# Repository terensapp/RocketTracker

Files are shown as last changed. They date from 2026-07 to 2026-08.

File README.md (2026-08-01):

# Rocket Tracker

A two-part GPS + LoRa tracker for finding your model rocket after it lands. A tiny transmitter rides inside the rocket, reads GPS once a second, and beams position + altitude over long-range radio to a handheld receiver that shows the live fix on an OLED screen and a phone-friendly web page with one-tap turn-by-turn navigation to the rocket.

No cellular network, no WiFi infrastructure, no subscription — just point-to-point radio that works in a farm field just as well as it works anywhere else.

## How it works

- **Transmitter** (rides in the rocket): reads lat/lon/altitude/satellite count/fix quality (HDOP)/battery level off a GPS module and its own sensors, and sends a 23-byte packet over LoRa once per second.
- **Receiver** (stays in your hand): listens for those packets, shows the latest fix (plus HDOP, so you know how much to trust it) plus height-above-pad and max-altitude-reached on a small OLED, and hosts its own WiFi hotspot with a web page — connect your phone to it and tap "Navigate to Rocket" (opens Google Maps) to walk straight to the rocket, or watch a live altitude graph of the flight so far. No power switch on the board, but holding the top PRG button for a second puts it to sleep (and pressing it again wakes it back up), so it isn't draining its battery between launches. It also shows the transmitter's battery level, which hitches a ride in every LoRa packet, so you can check there's plenty of charge before walking out to the pad. A "New Launch" button on the web page resets the altitude graph and baseline for the next flight, no power-cycling required.

Full technical detail — packet format, pin mappings, radio settings — is in [`SETUP_README.md`](SETUP_README.md) and in the comments at the top of each `.ino` file.

<p align="center">
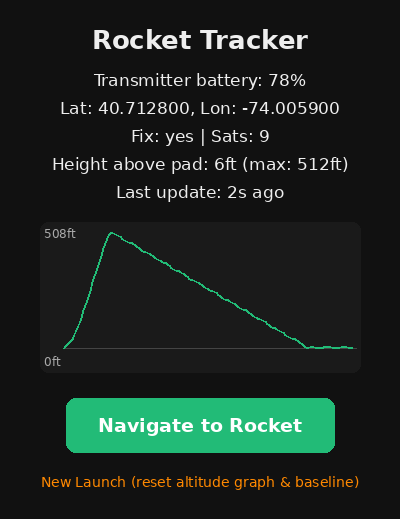
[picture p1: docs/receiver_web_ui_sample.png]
Sample of the receiver's web page, showing battery, GPS fix, altitude graph, and navigation button
  
</p>

<p align="center"><em>Illustrative mockup with sample flight data (not a real device screenshot) — shows the receiver's web page layout: battery, GPS fix, live altitude graph, and the "Navigate to Rocket" / "New Launch" buttons.</em></p>

## Repo contents

| Path | What it is |
| --- | --- |
| `rocket_transmitter/rocket_transmitter.ino` | Flashes onto the board that rides in the rocket (Feather M0 build) |
| `rocket_transmitter_wireless_tracker/rocket_transmitter_wireless_tracker.ino` | Alternative transmitter sketch for the smaller Heltec Wireless Tracker V2 build (recommended over CubeCell) |
| `rocket_transmitter_cubecell/rocket_transmitter_cubecell.ino` | Legacy alternative transmitter sketch for the CubeCell GPS build — see the note in its BOM section before buying this board |
| `rocket_receiver/rocket_receiver.ino` | Flashes onto the handheld receiver (works with any transmitter build) |
| `SETUP_README.md` | Step-by-step flashing and bench-test guide |
| `enclosures/transmitter_case.scad` | Parametric 3D-printable case for the Feather M0 transmitter stack |
| `enclosures/transmitter_case_wireless_tracker.scad` | Parametric 3D-printable case for the Wireless Tracker V2 transmitter |
| `enclosures/transmitter_case_cubecell.scad` | Parametric 3D-printable case for the CubeCell GPS transmitter (legacy) |

## Bill of Materials

Two boards, no soldering beyond an optional antenna wire. Prices are approximate and will drift.

### Transmitter (goes in the rocket) — ~$69

| Part | Price | Link |
| --- | --- | --- |
| Adafruit Feather M0 with RFM95 LoRa Radio (900MHz) | $34.95 | [adafruit.com/product/3178](https://www.adafruit.com/product/3178) |
| Adafruit Ultimate GPS FeatherWing | $24.95 | [adafruit.com/product/3133](https://www.adafruit.com/product/3133) |
| 3.7V 300mAh LiPo, generic "302040" size (3.0 x 20 x 40mm, JST-PH connector) — a standard size code widely sold on Amazon/AliExpress, not an Adafruit part; search "302040 300mAh lipo" | ~$7-9 | generic |
| 915MHz spring antenna — 17.5mm long, 2.15dBi gain, 50Ω impedance, solders directly to the board's ANT pad (or solder your own quarter-wave wire instead — the sketch comments explain the length) | $0.95 | [adafruit.com/product/4269](https://www.adafruit.com/product/4269) |
| Micro USB cable, for flashing | — | any micro USB cable |

Optional: a CR1220 coin cell ([adafruit.com/product/380](https://www.adafruit.com/product/380), $0.95) gives the GPS module a warm-start battery backup — not required, just speeds up subsequent fixes.

### Receiver (stays in your hand) — check listing for price

| Part | Price | Link |
| --- | --- | --- |
| Meshnology N30, 2-pack (ESP32-S3 + SX1262, includes 1100mAh battery + case + 915MHz antenna per unit) | check listing | [Amazon](https://www.amazon.com/V3-Development-1100mAh-Battery-Protect/dp/B0F1CXG94J) |
| USB-C cable, for flashing | — | any USB-C cable |

You only need one N30 for the receiver — the Amazon listing sells them as a 2-pack, so the second board makes a handy spare or a second ground unit. It ships as a kit (board, battery, case, antenna as separate pieces you assemble) rather than pre-built — expect a few minutes of snapping it together, not soldering.

**Region note:** both sketches default to 915MHz (US). Outside the US, buy 868MHz-band antennas instead and change `LORA_FREQ_MHZ` to `868.0` in both `.ino` files — see the "Frequency/region" note in `SETUP_README.md`.

### Optional: a case for the transmitter

`enclosures/transmitter_case.scad` is a 3D-printable case that holds the whole transmitter stack — board, battery, and a cutout for an inline power switch. See the "3D-printed transmitter case" section in [`SETUP_README.md`](SETUP_README.md) for details and printing notes.

### Alternative transmitter: Wireless Tracker V2 (smaller form factor, recommended)

If the Feather M0 stack is too tall to fit your airframe, `rocket_transmitter_wireless_tracker/rocket_transmitter_wireless_tracker.ino` is an alternative transmitter sketch for the **Heltec Wireless Tracker V2** — one small board with the MCU, LoRa radio (plus an RF front-end amplifier for extra range), and GNSS all built in, instead of three stacked boards. It sends the exact same packet format, so it works with the **same receiver sketch, unmodified**, and uses **RadioLib** — the same LoRa library the receiver already uses, unlike the CubeCell alternative below. This board also has a small onboard TFT display, which this sketch uses to show live GPS/radio status — handy for bench-testing outdoors on battery power without a laptop tethered for the Serial Monitor. The backlight is off by default to save battery; press the board's user button to check status before a launch, press again to turn it off. See "Alternative build: Wireless Tracker V2" in [`SETUP_README.md`](SETUP_README.md) for the full picture.

| Part | Price | Link |
| --- | --- | --- |
| Heltec Wireless Tracker V2 | ~$23–31 (compare Heltec's own store vs. Amazon/AliExpress resellers) | [heltec.org/project/wireless-tracker-v2](https://heltec.org/project/wireless-tracker-v2/) |
| 3.7V 300mAh LiPo, "302040" size — same JST-SH 1.25mm pitch connector as the CubeCell build | ~$7-9 | generic |
| Included spring LoRa antenna (ships with the board) — GNSS uses a built-in antenna on the board itself, no separate antenna needed for that | — | included |
| SS12D00-G4 mini slide switch, spliced inline into the battery lead — same part as the CubeCell build's switch mount | ~$3-6 for a pack | generic |
| USB-C cable, for flashing | — | any USB-C cable |

`enclosures/transmitter_case_wireless_tracker.scad` is the matching case — same snap-lid-and-glue closure, parachute tie tab, slim clearances, and rounded corners as the CubeCell case, sized for this board instead.

### Legacy alternative: CubeCell GPS

`rocket_transmitter_cubecell/rocket_transmitter_cubecell.ino` and `enclosures/transmitter_case_cubecell.scad` are still in this repo and still work, but **the Wireless Tracker V2 build above is recommended instead** for two reasons: Heltec lists the CubeCell ASR650x series as "Phaseout" on their own docs site, and this board's onboard GPS antenna has multiple independent weak/dead-on-arrival reports on Heltec's community forum. If you already have a CubeCell GPS board, it's documented in full in `SETUP_README.md`, including a workaround for the antenna issue.

| Part | Price | Link |
| --- | --- | --- |
| Heltec CubeCell GPS-6502 (HTCC-AB02S) | ~$25.80–25.90 | [heltec.org/project/htcc-ab02s](https://heltec.org/project/htcc-ab02s/) |
| 3.7V 300mAh LiPo, "302040" size — **check the connector**: this board uses JST-SH 1.25mm pitch, not the JST-PH 2.0mm pitch on the Feather build | ~$7-9 | generic |
| u.FL/IPEX stub antenna, 902-928MHz, 3dBi, direct-mount (no pigtail needed) | $6.49 | [DigiKey #1173-1023-ND](https://www.digikey.com/en/products/detail/ttm-technologies-inc/66089-0906/3069145) |
| SS12D00-G4 mini slide switch, spliced inline into the battery lead — a common generic part, search that name on Amazon/AliExpress/eBay; the case's switch pocket is sized to its body/lever dimensions (see `SETUP_README.md`) | ~$3-6 for a pack | generic |
| Micro USB cable, for flashing | — | any micro USB cable |

## Getting started

1. Buy the parts above.
2. Follow [`SETUP_README.md`](SETUP_README.md) for board packages, libraries, flashing steps, and a bench-test checklist — do the bench test before anything goes near a launch pad.
3. Fly, land, open the receiver's web page, tap navigate, go find your rocket.

## Status

The Feather M0 transmitter, the Wireless Tracker V2 transmitter, and the receiver are all compile-verified (Adafruit SAMD core / esp32 core, RadioLib/TinyGPSPlus/U8g2/Adafruit GFX+ST7735 — zero errors, zero warnings) but not yet flight-tested on real hardware. The CubeCell GPS transmitter alternative has also been compile-verified against the real CubeCell board package and toolchain (zero errors) — see the caveat about one packaging-only step in `SETUP_README.md`. Bench-test thoroughly before a launch, regardless of which transmitter build you use.

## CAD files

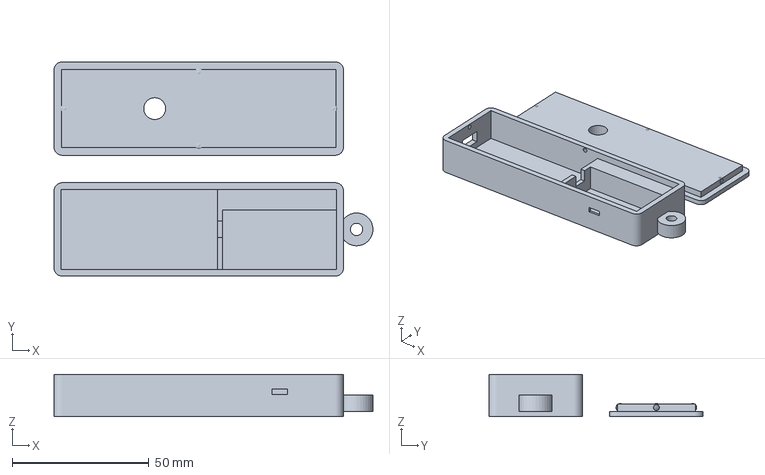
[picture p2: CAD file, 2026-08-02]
enclosures/transmitter_case_cubecell.3mf
116.5 x 78.2 x 15.5 mm

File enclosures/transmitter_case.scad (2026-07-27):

// ==========================================================================
// ROCKET TRACKER - TRANSMITTER CASE
// ==========================================================================
// Holds: Adafruit Feather M0 w/ RFM95 LoRa (900MHz, product 3178) with the
// Adafruit Ultimate GPS FeatherWing (product 3133) stacked on top, a 3.7V
// 300mAh LiPo (generic "302040" size, ~40 x 20 x 3mm - see battery bay
// section below), a hole for a spring antenna to poke through, and a
// panel-mount cutout for an inline power switch spliced into the battery
// lead.
//
// CLOSURE: the lid press-fits into a lip on the base, with 4 small snap
// bumps (see bump_r/bump_protrude) that give it a bit of a "click" and
// hold it shut for handling - it's meant to be glued the rest of the way
// once you've test-fit everything, not screwed. No screw bosses sticking
// out means a noticeably smaller footprint, which matters if this needs
// to fit down a rocket's airframe.
//
// RECOVERY: there's a molded tie tab on the battery-bay end with a round
// hole through it (see tie_hole_d) for a loop of paracord or shock cord,
// so the transmitter stays attached to the parachute/harness instead of
// becoming its own separate ballistic object on the way down.
//
// HOW TO USE THIS FILE
//   1. Open in OpenSCAD (openscad.org - free, all platforms).
//   2. Set the `part` variable below to "base" or "lid", press F6 (render),
//      then File > Export > Export as STL. Do this once for each part.
//   3. Leaving `part` set to "both" just previews them side by side so you
//      can see how everything lines up - don't export an STL in that mode,
//      the two parts would come out as one fused blob.
//
// IMPORTANT - DIMENSIONS ARE BEST-EFFORT, NOT MEASURED FROM YOUR HARDWARE
//   Board outline, header spacing, and connector positions below come from
//   Adafruit's published Feather specification and product pages, not from
//   calipers on your actual boards. The pocket and cutouts are sized with
//   generous clearance (see the *_fit variables) specifically so small
//   errors here don't turn into a part that doesn't fit. Even so: print the
//   base first, test-fit your actual boards and battery in it BEFORE
//   printing the lid or trimming any clearance down. Cheap, fast filament
//   (low infill, no supports needed for this design) makes a test print
//   painless compared to re-measuring everything by hand up front.
//
// WHERE THE ANTENNA EXITS
//   Adafruit's guide has you solder the antenna into the "ANT" pad on the
//   right-hand long edge of the Feather (USB connector oriented at the
//   top), positioned toward the end of the board opposite USB (that's
//   where the RFM95 radio module itself sits). The exit hole below is on
//   that same long edge, close to the far end - NOT on the far end wall
//   itself, because that wall is shared with the battery bay right next
//   to it, and the antenna's lead (about 17.5mm total) isn't long enough
//   to reach all the way across the battery bay to the case's true far
//   end. `ant_hole_y` controls exactly how close to the end it sits -
//   check where your antenna is actually soldered before printing.
// ==========================================================================

part = "both"; // "base", "lid", or "both" (preview only)

// ---------------------------------------------------------------------
// Feather board stack (M0 LoRa + GPS FeatherWing)
// ---------------------------------------------------------------------
feather_l          = 50.8;  // 2.0in - Feather board length (Adafruit spec)
feather_w          = 22.9;  // 0.9in - Feather board width
board_fit          = 1.0;   // clearance added around the board footprint
pcb_t              = 1.6;   // typical PCB thickness (both boards)
header_gap         = 8.6;   // vertical gap between the two boards once the
                             // GPS wing is plugged into standard-height
                             // female headers on the M0 - also has to fit
                             // the GPS wing's coin-cell holder on its
                             // underside, which is why this isn't tighter
under_board_clear  = 2.5;   // clearance below the M0 for solder joints/pins
top_stack_clear    = 7.0;   // clearance above the GPS wing for its patch
                             // antenna (~4mm tall) plus a little headroom

stack_h = under_board_clear + pcb_t + header_gap + pcb_t + top_stack_clear;

// Feather mounting holes: Adafruit's spec says "0.1in holes at each
// corner" - taken here as 2.54mm inset from every edge, giving the
// commonly-seen 1.8in x 0.7in (45.7 x 17.8mm) hole spacing. Worth
// double-checking against your actual board; these posts are support/
// registration features, not the only thing holding the stack in place.
hole_inset  = 2.54;
post_dia    = 6.0;   // support nub diameter at each estimated hole location
                      // (solid bumps the PCB rests on - not threaded, just
                      // support; add your own screw holes here if you've
                      // verified the real hole positions on your board)

// ---------------------------------------------------------------------
// Battery bay - sized for a 3.7V 300mAh LiPo, generic "302040" size code
// (a standard, widely-sold LiPo footprint - the digits are the physical
// dimensions: 3.0mm thick x 20mm wide x 40mm long). Not an Adafruit part
// number - these are commonly sold on Amazon/AliExpress with a JST-PH
// connector, search "302040 300mAh lipo". Swap batt_l/batt_w/batt_t below
// if your actual battery's printed dimensions differ.
// ---------------------------------------------------------------------
batt_l = 40.0;
batt_w = 20.0;
batt_t = 3.0;
batt_fit = 1.2; // clearance around the battery so it slides in easily

// ---------------------------------------------------------------------
// Case shell
// ---------------------------------------------------------------------
wall   = 2.5;   // a bit thicker than a typical small enclosure - this has
                 // to survive a parachute landing - but slim enough to
                 // help the whole thing fit down an airframe
floor  = 2.0;
lid_t  = 2.0;
lip_h  = 3.0;    // depth of the base's lip that the lid seats into
lip_gap = 0.3;   // general clearance between lid skirt and base lip, sized
                 // for an easy push-together fit - the snap bumps below
                 // are what actually give it resistance/a "click", not a
                 // tight fit across the whole perimeter (which is harder
                 // to guarantee across different printers)

// Small interference bumps on the lid's skirt (one per side, at the
// midpoint) that the base's lip has to flex slightly to accept - gives a
// "snap" you can feel going on, without relying on the whole perimeter
// being a precise press-fit. This is meant to hold the lid on for
// handling and a test-fit, then get glued for flight - not to be a
// resealable connector.
bump_r        = 1.5;  // bump sphere radius
bump_protrude = 0.35; // how far the bump sticks out past the skirt face

// Internal partition between the electronics bay and the battery bay -
// the battery's JST wire just runs over the top of it, no hole needed.
divider_w = 2.0;
divider_gap_h = 6.0; // leave a gap above the divider for the JST wire

// ---------------------------------------------------------------------
// USB cutout (micro USB on the Feather M0, top/short edge of the board)
// ---------------------------------------------------------------------
usb_w = 10.0;
usb_h = 5.0;
usb_offset = 6.0; // distance from the electronics-bay side wall to the
                   // near edge of the cutout - Feather's USB connector
                   // sits close to the left edge of the board; nudge this
                   // to match your board if it's off

// ---------------------------------------------------------------------
// Antenna exit hole (right-hand long edge of the Feather, near the end
// opposite USB - see "WHERE THE ANTENNA EXITS" at the top of this file).
// Sized for Adafruit's Simple Spring Antenna - 915MHz (product 4269):
// 17.5mm long, 0.8mm wire gauge wound into a coil - the coil's outer
// diameter isn't published, so ant_hole_d below is a generous estimate
// with clearance built in, not a measured fit.
// ---------------------------------------------------------------------
ant_hole_d = 5.0;
ant_hole_y = 0.9; // fraction along that edge's length - 0 = USB end,
                   // 1 = far/divider end. 0.9 keeps it close to the far
                   // end (where the radio module is) with a little margin
                   // from the corner for wall strength.
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

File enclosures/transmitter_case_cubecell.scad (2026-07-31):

// ==========================================================================
// ROCKET TRACKER - TRANSMITTER CASE (CubeCell GPS all-in-one alternative)
// ==========================================================================
// Holds: Heltec CubeCell GPS, HTCC-AB02S (one board - MCU, SX1262 LoRa radio,
// GPS, and OLED all integrated, no stacking), a 3.7V 300mAh LiPo (generic
// "302040" size), a hole for a u.FL/IPEX antenna pigtail to exit, and a
// keyed pocket that holds an SS12D00-G4 slide switch spliced into the
// battery lead. This is the companion case for rocket_transmitter_cubecell.ino
// - see enclosures/transmitter_case.scad instead if you're building the
// Feather M0 version (three-board stack, spring antenna soldered direct).
//
// WHY THIS IS SMALLER: the Feather M0 build stacks three boards (M0 + GPS
// FeatherWing + battery) with headroom between them for header pins and a
// patch antenna. CubeCell GPS puts the MCU, radio, and GPS on one board, so
// this case only needs to be as tall as one PCB plus its tallest connector,
// not a whole stack. Rough numbers: this case's footprint is about 34mm
// wide x 15.5mm tall, versus 30mm x 26mm for the Feather version - shallower,
// which matters more than raw length for sliding into a narrow airframe.
//
// SLIMMED DOWN + ROUNDED CORNERS: the board/battery pocket clearances
// (`board_fit`, `batt_fit`, `board_vert_clear`) were tightened to shave a
// couple mm off every outer dimension - still a snug hand-fit, not a
// press-fit, since this case is glued shut once and not reopened. The 4
// vertical corners are also rounded (`case_corner_r`) instead of sharp
// 90-degree edges - more comfortable to handle, and a rounded rectangle's
// bounding circle is smaller than a sharp one's, which helps it slide into
// a round airframe tube. Only the outer surfaces are rounded; every
// interior cavity (pockets, cutouts, lip/skirt) stays a plain rectangle,
// since they're all inset `wall` from the edges - comfortably clear of the
// rounding - and don't need to match it for anything to seat correctly.
//
// CLOSURE / RECOVERY: same snap-lid-and-glue closure and parachute tie tab
// as the Feather case - see that file's header comment for the reasoning,
// not repeated here. One difference: this case's snap bumps also have a
// matching detent dimple cut into the base's lip cavity for each one to
// seat into (see `bump_groove_r` below) - the Feather case's bumps just
// press against a flat wall, which is fine there but wasn't giving a
// reliable click on this smaller case, so a real detent was added here.
//
// HOW TO USE THIS FILE
//   1. Open in OpenSCAD (openscad.org - free, all platforms).
//   2. Set the `part` variable below to "base" or "lid", press F6 (render),
//      then File > Export > Export as STL. Do this once for each part.
//   3. Leaving `part` set to "both" just previews them side by side - don't
//      export an STL in that mode.
//
// IMPORTANT - DIMENSIONS ARE BEST-EFFORT, NOT MEASURED FROM YOUR HARDWARE
//   The board envelope (55.9 x 27.9 x 9.5mm) comes from Heltec's published
//   spec sheet for HTCC-AB02S, not calipers on your actual board. Print the
//   base first, test-fit before printing the lid.
//
// WHERE THE ANTENNA EXITS - READ THIS ONE CAREFULLY
//   Unlike the Feather build (a spring antenna soldered directly to a fixed
//   pad), CubeCell GPS has a u.FL/IPEX antenna connector - you'll need an
//   IPEX-pigtail antenna (see the BOM note in the README) rather than a
//   solder-in spring antenna. Heltec's pin map diagram shows roughly where
//   that connector sits, but wasn't precise enough to trust for a tight
//   side-wall cutout. So instead of guessing a side position and risking a
//   hole that misses the connector, the antenna hole below is cut through
//   the TOP of the LID, sized generously (8mm) and centered over the board
//   - the u.FL pigtail is a thin, flexible cable, so it can bend to reach an
//   opening almost anywhere above the board. Nudge `ant_hole_x_frac` /
//   `ant_hole_y_frac` below if your test-fit shows the connector is
//   noticeably off-center, but don't assume you need to before checking.
//
// WHERE THE SWITCH LIVES
//   The switch mount is a keyed pocket in the battery bay's front wall (the
//   long wall at y=0), centered along that bay's length - not on the end
//   wall the tie tab is bolted to. Earlier versions of this case put a
//   switch cutout on that end wall, right next to the tie tab, which looked
//   like a stray unexplained hole and put a hole through the same wall the
//   tie tab has to stay solid for. Moving it to the battery bay's side wall
//   fixes both problems. The pocket is two nested cuts: a narrow slot
//   through the outer face sized only for the slide lever to poke through
//   and travel in, and a wider, shallower pocket behind it (open to the
//   battery bay's interior) sized to capture the switch body. The body
//   can't pull out through the narrow outer slot, and two small retention
//   bumps (same idea as the lid's snap bumps, just smaller) protrude into
//   the pocket from its top and bottom faces - the switch body has to press
//   past them to seat, then they nest against its top/bottom face and hold
//   it with a "click", no glue required (though a dab is still fine if you
//   want extra insurance) - see the "Slide switch mount" parameters below
//   for the dimensions, taken from the SS12D00-G4
//   manufacturer drawing (body 8.7 x 3.7 x 3.7mm, lever 1.5 x 1.5 x 4mm).
//   The 3-pin through-hole legs on the underside of that switch aren't used
//   here - the switch is wired inline into the battery lead by hand, not
//   soldered to a PCB, so only the body and lever envelope matter for the
//   case. `sw_travel` is an assumed slide throw, not from the drawing (which
//   doesn't dimension it) - test-fit and adjust if your switch's actual
//   throw differs.
// ==========================================================================

part = "both"; // "base", "lid", or "both" (preview only)

// ---------------------------------------------------------------------
// CubeCell GPS board (HTCC-AB02S) - one-piece board, no stacking
// ---------------------------------------------------------------------
board_l   = 55.9;  // Heltec spec: overall board length
board_w   = 27.9;  // Heltec spec: overall board width
board_h   = 9.5;   // Heltec spec: overall board height, including the
                    // onboard OLED, connectors, and any other tallest part
board_fit = 0.6;    // clearance added around the board footprint - tightened
                     // from 1.0mm to slim the case down; still a snug hand-fit,
                     // not a press-fit, since this is glued shut once anyway
board_vert_clear = 1.0; // headroom above the board's tallest point - was 1.5mm

pocket_h = board_h + board_vert_clear;

// No verified mounting-hole spec is published for this board, so this
// design deliberately skips screw-post nubs (unlike the Feather case, which
// had Adafruit's documented hole spacing to work from) rather than guess
// hole positions that might be wrong. The board is held by a snug pocket
// fit in X/Y and the lid's underside in Z - fine for a glued-shut case that
// isn't opened repeatedly. Add your own posts here if you've measured your
// actual board's mounting holes.

// ---------------------------------------------------------------------
// Battery bay - sized for a 3.7V 300mAh LiPo, generic "302040" size code
// (3.0mm thick x 20mm wide x 40mm long). Same battery as the Feather build
// - see that file's comment for sourcing notes. One difference: CubeCell
// GPS's onboard battery connector is JST-SH 1.25mm pitch (2-pin), NOT the
// JST-PH 2.0mm pitch used on the Feather - double check which connector
// your battery actually ships with (see the BOM note) before ordering.
// ---------------------------------------------------------------------
batt_l = 40.0;
batt_w = 20.0;
batt_t = 3.0;
batt_fit = 0.8; // was 1.2mm - tightened along with board_fit to slim the case

// ---------------------------------------------------------------------
// Case shell
// ---------------------------------------------------------------------
wall   = 2.5;
floor  = 2.0;
lid_t  = 2.0;
lip_h  = 3.0;
lip_gap = 0.3;
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

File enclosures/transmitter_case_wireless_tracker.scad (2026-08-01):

// ==========================================================================
// ROCKET TRACKER - TRANSMITTER CASE (Heltec Wireless Tracker V2 alternative)
// ==========================================================================
// Holds: Heltec Wireless Tracker V2 (one board - ESP32-S3 MCU, SX1262 LoRa
// radio + RF front-end amplifier, UC6580 GNSS, and TFT display all
// integrated, no stacking), a 3.7V 300mAh LiPo (generic "302040" size), a
// hole for the LoRa antenna to exit, and a keyed pocket that holds an
// SS12D00-G4 slide switch spliced into the battery lead. This is the
// companion case for rocket_transmitter_wireless_tracker.ino - see
// enclosures/transmitter_case.scad (Feather M0) or
// enclosures/transmitter_case_cubecell.scad (CubeCell GPS, legacy) for the
// other two transmitter builds in this repo.
//
// WHY THIS BOARD INSTEAD OF CUBECELL: CubeCell GPS is on Heltec's own
// "Phaseout" list, and its onboard GPS antenna has multiple independent
// weak/dead-on-arrival reports. Wireless Tracker V2 uses a different,
// better-regarded GNSS chip (UC6580) and is an actively-sold, actively-
// supported product - see SETUP_README.md for the full comparison.
//
// GNSS ANTENNA - NO HOLE NEEDED FOR IT
// Unlike the CubeCell case, this one only has ONE antenna hole, for LoRa.
// This board's GNSS antenna is a built-in LDS (laser-direct-structuring)
// antenna etched right onto the board - no external antenna or hole needed
// for normal use. If you ever do the resistor-rework Heltec documents for
// switching to an external GNSS antenna, you'd need to add a second hole
// yourself - not included here since it's not needed by default.
//
// WHERE THE LORA ANTENNA EXITS
// Cut through the TOP of the LID, same reasoning as the CubeCell case:
// Heltec doesn't publish a precise connector position, and the included
// antenna has some flex in its stub, so a generous, centered top hole
// avoids needing to guess an exact side-wall position that might miss.
// Nudge `ant_hole_x_frac` / `ant_hole_y_frac` below if your test-fit shows
// the connector is noticeably off-center.
//
// HOW TO USE THIS FILE
//   1. Open in OpenSCAD (openscad.org - free, all platforms).
//   2. Set the `part` variable below to "base" or "lid", press F6 (render),
//      then File > Export > Export as STL. Do this once for each part.
//   3. Leaving `part` set to "both" just previews them side by side - don't
//      export an STL in that mode.
//
// IMPORTANT - DIMENSIONS ARE BEST-EFFORT, NOT MEASURED FROM YOUR HARDWARE
//   The board envelope (53.0 x 25.4 x 10.3mm) is the larger of two
//   slightly-different numbers Heltec publishes for this board across
//   their store page and docs wiki - taken conservatively so the pocket
//   errs on the roomy side. Print the base first, test-fit before printing
//   the lid.
//
// WHERE THE SWITCH LIVES
//   Same keyed-pocket switch mount as the CubeCell case, same SS12D00-G4
//   part, same reasoning - see that file's header comment if you want the
//   full explanation. Quick summary: a narrow outer slot for the slide
//   lever only, a wider inner pocket for the switch body (captured, can't
//   pull through the narrow slot), and two small retention bumps that snap
//   the body in place with a "click." Centered on the battery bay's front
//   wall, away from the tie tab.
// ==========================================================================

part = "both"; // "base", "lid", or "both" (preview only)

// ---------------------------------------------------------------------
// Heltec Wireless Tracker V2 board - one-piece board, no stacking
// ---------------------------------------------------------------------
board_l   = 53.0;  // larger of Heltec's two published lengths (52.0/53.0)
board_w   = 25.4;  // Heltec spec: overall board width
board_h   = 10.3;  // larger of Heltec's two published heights (9.37/10.26),
                    // including the TFT glass, USB-C connector, and the
                    // shielded LoRa/GNSS chip cans
board_fit = 0.6;    // clearance added around the board footprint - snug
                     // hand-fit, not a press-fit, fine for a glued-shut case
board_vert_clear = 1.5; // headroom above the board's tallest point - a bit
                         // more than the CubeCell case's, since this board
                         // has more raised hardware (USB-C, shield cans,
                         // TFT) and its exact height breakdown isn't published

pocket_h = board_h + board_vert_clear;

// No verified mounting-hole spec is published for this board, so - same as
// both other cases in this repo - this design skips screw-post nubs and
// relies on a snug pocket fit in X/Y and the lid's underside in Z. Add your
// own posts here if you've measured your actual board's mounting holes.

// ---------------------------------------------------------------------
// Battery bay - sized for a 3.7V 300mAh LiPo, generic "302040" size code
// (3.0mm thick x 20mm wide x 40mm long). Same battery and same JST-SH
// 1.25mm pitch connector as the CubeCell build - see that file's comment
// for sourcing notes.
// ---------------------------------------------------------------------
batt_l = 40.0;
batt_w = 20.0;
batt_t = 3.0;
batt_fit = 0.8;

// ---------------------------------------------------------------------
// Case shell
// ---------------------------------------------------------------------
wall   = 2.5;
floor  = 2.0;
lid_t  = 2.0;
lip_h  = 3.0;
lip_gap = 0.3;

// Rounded corners - see the CubeCell case's comment for the full reasoning
// (comfort + helps sliding into a round airframe tube). Carried over here
// from day one instead of being a later retrofit.
case_corner_r = 3.0;

bump_r        = 1.5;
bump_protrude = 0.5;   // net interference tuned the same way as the
                        // CubeCell case's lid bumps - see that file's
                        // comment for why 0.5 instead of a smaller value
bump_groove_r     = 1.1;
bump_groove_depth = 0.65;
bump_groove_inset = bump_groove_r - bump_groove_depth;

divider_w = 2.0;
divider_gap_h = 5.0; // gap above the divider for the battery's JST wire to
                      // cross over

// ---------------------------------------------------------------------
// USB-C cutout - generously sized (same envelope as the CubeCell case's
// micro-USB cutout, which comfortably fits USB-C's slightly larger
// connector body too).
// ---------------------------------------------------------------------
usb_w = 10.0;
usb_h = 5.0;
usb_center_bias = 0.0; // mm to shift the cutout off-center, + = toward the
                        // battery/divider end - nudge if your board's port
                        // isn't centered on the board width
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

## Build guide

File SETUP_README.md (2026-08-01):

# Rocket Tracker — Setup Guide

Two sketches:

- `rocket_transmitter/rocket_transmitter.ino` — flashes onto the **Adafruit Feather M0 + RFM95 LoRa (900MHz) + GPS FeatherWing** stack. Lives in the rocket.
- `rocket_receiver/rocket_receiver.ino` — flashes onto the **Meshnology N30 (ESP32-S3 + SX1262)**. Handheld unit.

Both sketches have been compile-verified against the real toolchain (Adafruit SAMD core + esp32 core, RadioLib/TinyGPSPlus/U8g2) — zero errors, zero warnings. Compilation only proves the code builds, though, not that it works on real hardware — do the bench test in step 6 before anything goes near a launch pad.

## 1. Install Arduino IDE

Download from arduino.cc if you don't have it already (2.x recommended).

## 2. Install board packages

**File > Preferences > Additional Board Manager URLs**, add both (comma-separated, or one per line depending on your IDE version):

```
https://adafruit.github.io/arduino-board-index/package_adafruit_index.json
https://raw.githubusercontent.com/espressif/arduino-esp32/gh-pages/package_esp32_index.json
```

The Adafruit URL is required for the transmitter's board — without it, "Adafruit SAMD Boards" won't show up in Boards Manager at all.

Then **Tools > Board > Boards Manager**:

- Install **"Adafruit SAMD Boards"** (for the transmitter)
- Install **"esp32" by Espressif Systems** (for the receiver)

## 3. Install libraries

**Tools > Manage Libraries**, install:

- `RadioLib` (Jan Gromeš) — used by both sketches
- `TinyGPSPlus` (Mikal Hart) — transmitter only
- `U8g2` (oliver) — receiver only

## 4. Flash the transmitter

1. Plug the Feather M0 (with the GPS FeatherWing already stacked on top) into USB.
2. **Tools > Board** → select "Adafruit Feather M0"
3. Select the right **Port**
4. Open `rocket_transmitter.ino`, hit Upload
5. Open Serial Monitor at 115200 baud — you should see it printing GPS status. Note: it'll report `fix=0` indoors/near windows until it gets a clear sky view; GPS can take 30 seconds to a few minutes on a cold start.

## 5. Flash the receiver

1. Plug the Meshnology N30 into USB-C.
2. **Tools > Board** → select "ESP32S3 Dev Module"
3. Select the right **Port**. If you want Serial Monitor output over the same USB-C cable, also set **Tools > USB CDC On Boot > Enabled** (this board uses ESP32-S3's native USB, so without this setting the serial output has nowhere to go).
4. Open `rocket_receiver.ino`, hit Upload
5. The OLED should light up and show "Waiting for signal..." — if it stays blank, see the pin troubleshooting note below.

## 6. Test on the bench before flying

1. Power both boards up near each other.
2. The transmitter's onboard LED should blink briefly once per second (each successful send).
3. The receiver's OLED should update with lat/lon once the transmitter has a GPS fix — try this near a window or outdoors, GPS won't get a fix indoors.
4. On your phone, connect to WiFi network `RocketTracker` (password `findmyrocket`), then open `http://192.168.4.1` in a browser. You should see the coordinates and a green "Navigate to Rocket" button — tapping it always opens Google Maps (the app if it's installed, otherwise the website), regardless of phone.
5. Walk the transmitter away from the receiver in a straight line to get a rough real-world range estimate before your first launch. Don't assume the spec-sheet range — trees, buildings, and antenna orientation all matter.

## Altitude

GPS gives you altitude for free alongside lat/lon, so the receiver now shows it two ways:

- **Height above pad** — the receiver treats the *first* valid fix it ever receives as ground level, then reports everything after that as a delta from it. This is far more useful mid-search than raw GPS altitude (which is Mean Sea Level, an unfamiliar number tied to your local elevation, not the rocket's).
- **Max height reached** — since altitude is already streaming in every second, tracking the highest value seen is essentially free apogee tracking, no separate altimeter needed.

**This means the transmitter needs to be powered on while the rocket is already sitting on the pad, before launch** — that's the moment its GPS altitude becomes the "zero" baseline. Both the OLED and the web page show "H:" (height above pad) and "Max:" once a baseline is set; before that, they fall back to showing raw MSL altitude.

Two honest caveats: GPS altitude is less accurate than horizontal position — commonly off by 30-50 feet without differential correction — so treat this as a rough estimate, not a precision altimeter reading. Also, the baseline and max height both reset if the receiver reboots, so if you're running multiple flights in a day, power-cycle the receiver right before each new launch to re-zero it.

Everything shown to you — on the OLED, the web page, and in this guide — is in feet. Internally the GPS and the radio packet still use meters (that's what GPS hardware natively reports), the conversion just happens once, right before anything gets displayed.

### Live altitude graph

Sample of the receiver's web page with the altitude graph

*Illustrative mockup with sample flight data, not a real device screenshot — shows roughly what the web page looks like once you have a flight logged.*

The web page also draws a running graph of height-above-pad for the whole flight so far — no separate app, it's a plain HTML5 canvas the receiver draws itself, since the phone has no internet access while connected to the receiver's hotspot (a CDN-hosted charting library just wouldn't load). The graph, the max-height reading, and the altitude baseline all reset together — either by power-cycling the receiver, or by tapping **New Launch** at the bottom of the web page, which is the faster option if you're running multiple flights in a day.

The receiver keeps up to 30 minutes of altitude history per flight (one point per second, ~7KB of RAM — this board has hundreds of KB free, so it's not a real constraint). If a flight somehow runs past that, new points stop recording rather than erasing the earlier ones, so you still keep the actual ascent/descent profile instead of losing it.

## GPS precision

Both the OLED and the web page now show **HDOP** (horizontal dilution of precision) next to the fix — this is the actual accuracy number, separate from "has a fix" or satellite count. A GPS can report a valid fix with 9 satellites and still be wandering around by 10-20m if those 9 satellites are all bunched up in one part of the sky (poor geometry = high HDOP); the same fix with fewer, better-spread satellites can be accurate to a couple meters (low HDOP). Rough guide: under 2 is good, 2-5 is usable, over 5 means treat the position as a rough estimate even though it says "fix."

If HDOP is consistently high (readings feel imprecise even with a solid fix), a few things actually move the needle, roughly in order of impact:

- **Antenna quality.** By far the biggest lever, and worth trying first. The CubeCell build's onboard antenna specifically has multiple independent reports (Heltec's own community forum) of being weak — see the "no GPS fix" troubleshooting section above. A cheap external active GPS antenna, wired to the board's dedicated GPS u.FL connector, directly improves signal-to-noise, which directly improves HDOP, not just whether you get a fix at all. The Feather build's Ultimate GPS FeatherWing has a much better stock antenna, so this matters more for the CubeCell alternative.
- **Sky view.** Partial obstruction (trees, buildings, being near a window rather than fully outside) doesn't just delay a fix, it degrades it — reflected/multipath signal is a major source of position error. Test somewhere with a clear view of as much sky as possible.
- **Let it settle.** Position accuracy typically keeps improving for a minute or two after a GPS first reports "fix" — it's still locking onto more satellites and refining its solution. If you check HDOP the moment "Fix:Y" first appears, give it another minute or two before judging.
- **Altitude is inherently less precise than lat/lon**, for any single-frequency consumer GPS — commonly off by 30-50 feet regardless of HDOP or antenna (see the "Altitude" section above). This isn't something a better setup meaningfully fixes; it's a physical limitation of the GPS technique itself.

## Battery status

The transmitter's battery level shows up on the receiver's screen and web page ("TX Batt: 82%"), so you can check "is there plenty of charge for this flight" before you walk out to the pad. The Feather M0 measures its own LiPo voltage (built into the board, no extra hardware) and rides it along in every LoRa packet it already sends once a second — this works from the moment it powers on, even before GPS gets a fix, since it doesn't depend on GPS at all.

This is a LiPo voltage estimate (single-cell, nonlinear discharge curve), not a lab-grade fuel gauge — treat it as "plenty," "getting low," or "charge before flying," not a precise number. A reading below 20% shows a "!" next to it on the OLED and highlights red on the web page.

There's no equivalent reading for the receiver's own battery. That was tried (reading the ESP32-S3's own battery-sense pin locally, no radio needed) and removed: on a real N30 unit, that pin measured a flat 0V on a multimeter even with a fully-charged, healthy battery connected — the sense signal simply isn't wired through to that pin on this board, and no firmware fix could work around it. If you want to check the receiver's own battery, a multimeter across the JST connector is the reliable way (a healthy single-cell LiPo reads roughly 3.7-4.2V).

## Power (receiver)

The receiver has no physical power switch, but it does have two buttons, and only one of them is usable for this:

- **PRG (top button)** is wired to a real GPIO (GPIO0). Hold it for 1 second and the receiver shows "Powering down..." then drops into deep sleep - LoRa radio, OLED, and WiFi hotspot all powered down to a few microamps. Press PRG again and it wakes up with a full reboot, same as a fresh power-on.
- **Reset (bottom button)** is hardwired straight to the chip's reset line in hardware. It never passes through your code, so it can only ever do an instant hard reboot - it can't be used as a sleep/wake button.

Use PRG to put the receiver to sleep whenever it's not in use, so the battery isn't draining on the shelf between launches. The transmitter doesn't have this option - it needs a physical inline switch or battery disconnect if you want to store it powered off, since the Feather M0 only has a hard reset button.

## Confirming what's actually flashed

Two different timestamps, two different jobs:

- **The `Version:` line at the top of each `.ino` file** is stamped with when the source was actually last pushed (e.g. "pushed 2026-07-26 03:07 UTC"), visible the instant you open the file in the editor - no compiling needed. This is "when was this code actually written," which matters if you write code and don't get around to flashing it until hours or days later.
- **"Firmware built: Jul 25 2026 14:32:10"**, printed to Serial Monitor at boot and filled in automatically by the compiler, is "when was THIS PARTICULAR UPLOAD compiled" - i.e., what's actually running on the board right now. The receiver also shows its build date on the OLED splash screen for a few seconds at boot, so you can confirm it without a laptop plugged in.

If those two ever disagree by more than a few minutes, it means you edited the source after the last time you compiled and flashed - a nudge to re-upload before you trust what's on the board.

## Things to double-check / likely friction points

- **Pin mapping on the receiver.** The code uses the standard Heltec WiFi LoRa 32 V3 pin layout (LoRa on SPI pins 8–14, OLED on I2C pins 17/18, Vext power-gate on pin 36). The Meshnology N30 is built on that same architecture, but since it's a clone, cross-check against the pinout diagram on the product listing before your first flash. If the OLED stays blank or the radio fails to initialize, this is the first place to look.
- **Frequency/region.** Both sketches default to 915MHz (US). If you're outside the US, change `LORA_FREQ_MHZ` to `868.0` in **both** sketches, and make sure the antennas you bought match that band.
- **Sync word, spreading factor, bandwidth, coding rate** must be identical on both sketches — they already are by default, just don't change one without the other if you tune settings later.
- **GPS cold start.** First fix after power-on can take a couple minutes. Don't launch until the transmitter's serial output (or a blinking pattern you add) confirms `fix=1`.
- **Antenna orientation matters more than people expect** for LoRa range — keep both antennas vertical and don't wrap the transmitter's wire antenna around anything metal.
- **RadioLib version.** Both sketches were written against the current RadioLib API (v6.x). If you already have an older RadioLix installed, update it via Library Manager first.

## 3D-printed transmitter case

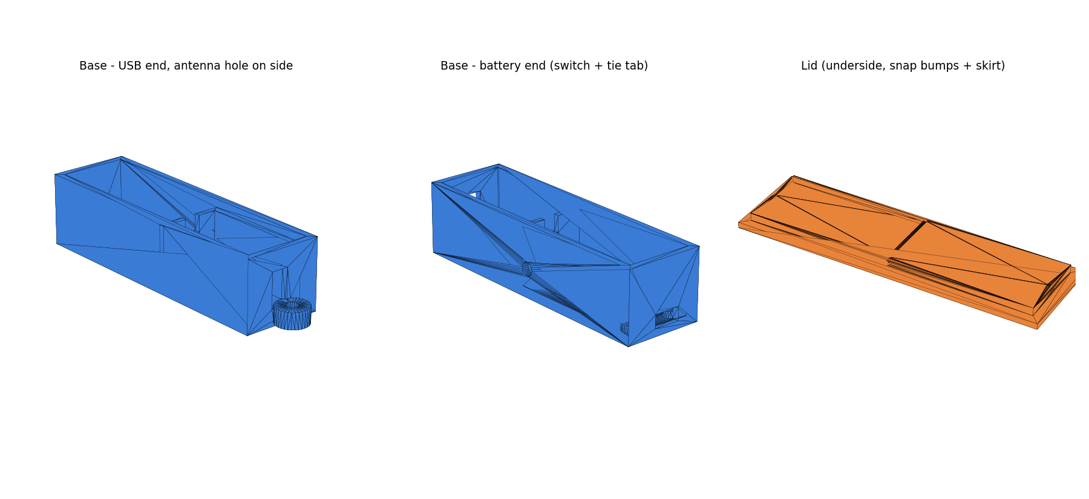
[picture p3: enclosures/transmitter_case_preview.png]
Preview of the transmitter case, base and lid


`enclosures/transmitter_case.scad` is a parametric [OpenSCAD](https://openscad.org) enclosure for the transmitter stack: a pocket for the Feather M0 + GPS FeatherWing, a bay for a 300mAh "302040" LiPo, a USB cutout for flashing/charging, a hole for the antenna to poke through, and a panel-mount cutout for an inline power switch spliced into the battery lead (the transmitter has no on/off switch of its own — see "Power (receiver)" above for why one helps here too).

The lid press-fits onto the base with a lip and 4 small snap bumps that give it a "click" and hold it shut for handling — no screws sticking out, which keeps the footprint smaller for fitting down an airframe. It's meant to be glued shut once you've test-fit everything and are happy with it, not re-opened repeatedly. There's also a molded tie tab on the battery-bay end with a ~4.5mm hole through it, for tying the transmitter to the parachute or recovery harness with paracord or shock cord — so it comes down attached to the rocket instead of becoming its own separate object in the air.

**Read the comments at the top of the file before printing.** The board/header/connector dimensions come from Adafruit's published specs, not calipers on your actual hardware, so a few things (USB cutout position, antenna slot position, mounting-hole spacing) are best-effort estimates with generous built-in clearance. Print the base first, test-fit your actual boards and battery, and nudge the relevant variable at the top of the file if something's off before printing the lid.

To use it: open the file in OpenSCAD, set the `part` variable near the top to `"base"` or `"lid"`, press F6 to render, then export as STL — do this once for each part. Leaving `part` set to `"both"` just previews them side by side.

## Alternative build: Wireless Tracker V2 (smaller transmitter, recommended)

`rocket_transmitter_wireless_tracker/rocket_transmitter_wireless_tracker.ino` is a second transmitter sketch, for the **Heltec Wireless Tracker V2** (ESP32-S3 + SX1262 LoRa radio with an RF front-end amplifier + UC6580 GNSS + 0.96" TFT, all on one board) instead of the Feather M0 stack. Same job, same 23-byte packet, works with the **same receiver sketch unchanged** — pick whichever transmitter build suits your rocket, you don't need both.

This is the recommended small-form-factor build — see "Legacy alternative: CubeCell GPS" further down for why the older CubeCell option isn't recommended anymore.

### Why smaller

The Feather M0 build stacks three boards (MCU+radio, GPS wing, battery) with headroom between them for header pins and a patch antenna. Wireless Tracker V2 puts the MCU, radio, and GNSS on one ~53 x 25.4 x 10.3mm board — no stacking. The matching case (`enclosures/transmitter_case_wireless_tracker.scad`) comes out to roughly 103 x 32 x 17mm — notably narrower than the Feather case, which matters most for sliding into a narrow airframe.

### Radio compatibility with the existing receiver

Unlike CubeCell, this board uses **RadioLib directly** — the exact same library the receiver already uses, against the same SX1262 chip, with the same pin-naming convention the receiver's Meshnology N30 board happens to share (CS/DIO1/RESET/BUSY/SCK/MISO/MOSI all identical numbers). No cross-library sync-word/coding-rate translation table needed like the CubeCell sketch requires — both sides just need to agree on frequency (915MHz), bandwidth (125kHz), spreading factor (SF9), coding rate (4/7), and sync word (0x12), all matched already.

One extra wrinkle this board has that the receiver doesn't: an external RF front-end chip (KCT8103L) between the SX1262 and the antenna, which is what gets this board's LoRa range up past a plain SX1262's ceiling. Three GPIOs power and enable it once at boot (see the comments at the top of the `.ino` file) — nothing you need to touch, just worth knowing it's there if you're comparing this sketch's `setup()` to the receiver's.

### Board package and flashing

1. **File > Preferences > Additional Board Manager URLs**, add:
   ```
   https://espressif.github.io/arduino-esp32/package_esp32_index.json
   ```
2. **Tools > Board > Boards Manager** > install **"esp32"** (by Espressif Systems)
3. Select board: **"ESP32S3 Dev Module"**
4. **Tools > USB CDC On Boot: "Enabled"** — needed to see Serial output over the USB-C port without a separate UART adapter
5. **Library Manager**, install: **RadioLib** (Jan Gromes), **TinyGPSPlus** (Mikal Hart), **Adafruit GFX Library**, and **Adafruit ST7735 and ST7789 Library** (both Adafruit) — the first two are already installed if you've set up the Feather or receiver sketches; the two display libraries are new for this build (the CubeCell and Feather builds use a different, OLED-only display library).
6. Open `rocket_transmitter_wireless_tracker.ino`, hit Upload.

### Compile verification

This sketch has been compiled clean against the real esp32-s3 toolchain (esp32 core 3.3.11, RadioLib, TinyGPSPlus, Adafruit GFX + ST7735) — zero errors, zero warnings. The pin map it's built from (LoRa, GNSS, display, battery ADC, RF front-end control) comes from Meshtastic's published, community-tested firmware source for this exact board, not a guess from a datasheet — but the GPS fix behavior, display rendering, and RF front-end sequencing haven't been exercised on real hardware yet the way the Feather build has. Bench-test thoroughly before a launch.

### Battery connector and antenna

Same **JST-SH, 1.25mm pitch** battery connector as the CubeCell build (not the JST-PH 2.0mm pitch on the Feather build) — the same "302040" 300mAh LiPo works, just double-check the connector on your specific battery listing. The board ships with a LoRa antenna in the box; the GNSS antenna is built directly into the board (an LDS antenna etched onto the PCB) and needs nothing else connected for normal use.

### Status button

The TFT backlight is off by default to save battery — the display keeps updating in the background either way, so the moment you press the board's user/PRG button, it shows current status immediately, no lag. Press again to turn the backlight back off. Same routine as the CubeCell build: power on, give the GPS a few minutes outdoors, press the button and confirm a real fix before it goes in the rocket, press again before closing up the case.

### Case

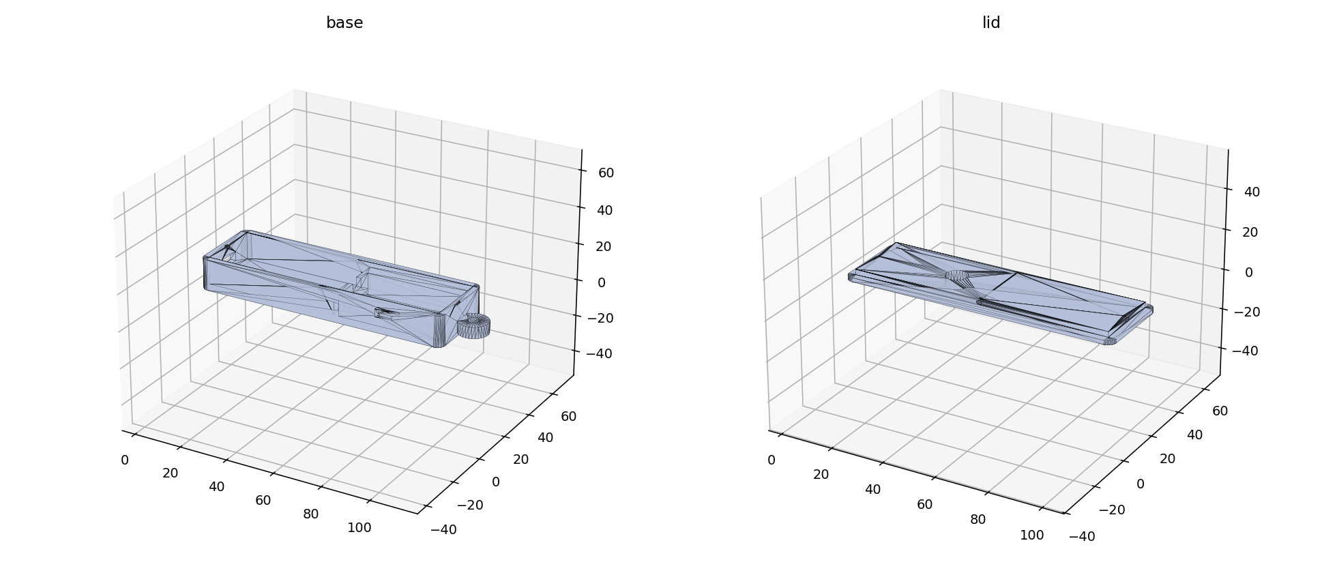
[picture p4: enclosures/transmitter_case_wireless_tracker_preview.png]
Preview of the Wireless Tracker V2 transmitter case


`enclosures/transmitter_case_wireless_tracker.scad` follows the same conventions as the CubeCell case — snap-lid-and-glue closure with a real detent click, parachute tie tab, slim clearances, rounded corners, and the same SS12D00-G4 keyed switch mount — just resized for this board. One difference: it only has **one** antenna hole (through the lid, same reasoning as the CubeCell case — a generous, centered hole rather than guessing an exact side-wall position), since the GNSS antenna doesn't need one at all by default. As always: print the base first, test-fit your actual board, battery, and switch before printing the lid.

## Legacy alternative: CubeCell GPS (smaller transmitter)

`rocket_transmitter_cubecell/rocket_transmitter_cubecell.ino` is a third transmitter sketch, for the **Heltec CubeCell GPS (HTCC-AB02S)** instead of the Feather M0 stack. Same job, same 23-byte packet, works with the **same receiver sketch unchanged** — pick whichever transmitter build suits your rocket, you don't need all three.

**The Wireless Tracker V2 build above is recommended over this one** for two reasons: Heltec's own docs site lists the CubeCell ASR650X series as "Phaseout" — their term for discontinued/end-of-life — and this board's onboard GPS antenna has multiple independent weak/dead-on-arrival reports on Heltec's community forum (see the troubleshooting section below if you already have one and are chasing a no-fix issue). This section is kept for anyone who already bought the board or wants the option anyway.

### Why smaller

The Feather M0 build stacks three boards (MCU+radio, GPS wing, battery) with headroom between them for header pins and a patch antenna. CubeCell GPS puts the MCU, SX1262 radio, and GPS on one 55.9 x 27.9 x 9.5mm board — no stacking. The matching case (`enclosures/transmitter_case_cubecell.scad`) comes out to roughly 34mm wide x 15.5mm tall, versus 30mm x 26mm for the Feather case — shallower, which matters more than raw length for sliding into a narrow airframe.

### Radio compatibility with the existing receiver

The receiver uses RadioLib against an SX1262. CubeCell's board package doesn't support RadioLib, so this sketch uses Heltec's own raw point-to-point LoRa driver instead (not full LoRaWAN — no gateway involved, just direct radio-to-radio, same idea as RadioLib's send/receive). Two different libraries can still talk to each other because LoRa is a physical-layer standard: as long as both sides agree on frequency (915MHz), bandwidth (125kHz), spreading factor (SF9), coding rate (4/7), and sync word (0x12), it doesn't matter whose software is driving the radio chip. All five are matched between the two sketches already — the comments at the top of `rocket_transmitter_cubecell.ino` explain exactly how each one maps between the two libraries' different naming/numbering conventions, in case you ever change one and need to update the other.

### Board package and flashing

1. **File > Preferences > Additional Board Manager URLs**, add:
   ```
   https://resource.heltec.cn/download/package_CubeCell_index.json
   ```
2. **Tools > Board > Boards Manager** > install **"CubeCell"**
3. Select board: **"CubeCell-GPS(HTCC-AB02S)"**
4. No extra libraries to install — the radio and GPS support ship inside the CubeCell board package itself.
5. Open `rocket_transmitter_cubecell.ino`, hit Upload.

### Compile verification — one honest caveat

This sketch has been compile-and-link verified against the real CubeCell board package (v1.4.0) and a real ARM cross-compiler — zero errors. There's one gap in that verification worth knowing about: producing the final `.cyacd` file (Heltec's proprietary format their flashing tool expects) requires a packaging utility that Heltec only ships as an x86_64 Linux/Mac/Windows binary, which the sandbox this was verified in couldn't run. That utility only repackages an already-correctly-compiled program into their upload format — it doesn't affect whether the code itself is correct — but it does mean the very last step (does the Arduino IDE's own Upload button produce a working `.cyacd` on your machine) hasn't been exercised end-to-end the way the Feather/receiver sketches have. On a normal desktop running the Arduino IDE, this isn't a concern at all — that packaging tool runs fine there, this caveat is purely an artifact of the sandboxed environment used to check the code.

### Battery connector — check before ordering

CubeCell GPS's onboard battery connector is **JST-SH, 1.25mm pitch** — not the JST-PH 2.0mm pitch used on the Feather build. The same "302040" 300mAh LiPo size works fine, but double-check which connector your specific battery listing ships with before ordering (some sellers offer both).

### Antenna — different connector than the Feather build

The Feather build solders a spring antenna directly to a pad. CubeCell GPS instead has a **u.FL/IPEX connector**, so you need a u.FL-compatible antenna (a direct-mount stub, or a u.FL-to-SMA pigtail plus a separate SMA antenna) rather than a solder-in one — see the BOM in the main README for a specific part.

### Troubleshooting: receiver shows "Sats: 0 Fix: N"

That just means the transmitter hasn't gotten a GPS fix yet, but that alone can't tell you whether the GPS chip is actually working.

**Easiest check: the transmitter's own onboard OLED.** It shows live status with no laptop needed, so you can take the board outside on battery power alone and read it directly — no need to keep it tethered to a computer to test it outdoors. The second line reads `chip: NO DATA` (the GPS chip isn't sending anything — a wiring/board problem), `chip: searching` (chip's working fine, just hasn't locked a fix yet — an antenna/sky-view/time problem, not a bug), or `chip: OK` (has a fix). The screen also shows sats count, GPS char count, battery %, and the last packet sent.

**The screen is off by default, to save battery** — press the board's user button (silkscreened "PRG" on some units) once to turn it on, press again to turn it off. Good pre-launch routine: power the board on, give the GPS a few minutes, press the button and confirm `chip: OK` with a real fix before it goes in the rocket, then press again to turn the screen off before closing up the case. It always starts off on a fresh boot — the on/off state itself isn't remembered across power cycles.

If you'd rather use the Serial Monitor, open it on the **transmitter** (not the receiver) at 115200 baud and check the same two things the OLED is built from:

1. **At boot**, before "Radio ready..." prints, the GPS library prints its own baud-detection log (`GPS Current baudrate detecting...` → `GPS Current baudrate detected: 9600` → `GPS baudrate updated to 9600`). If you see `GPS baudrate updated failed` instead, the chip isn't responding at the hardware level — that's a wiring/board problem, not a "needs more time" problem.
2. **Every second**, the transmitter also prints `GPS chars=<N> sentencesWithFix=<N> checksumFail=<N>`. If `chars` is stuck at 0, no data is arriving from the GPS chip at all (same hardware problem as above). If `chars` is counting up but `sentencesWithFix` stays at 0, the chip is working fine and just hasn't locked a fix — that's an antenna/sky-view/time problem, not a bug.

If it's the second case, a few things worth knowing (from the Heltec community forum, multiple independent reports):

- **First fix can take a long time** — one documented case took over an hour before the first fix, a few minutes on subsequent power-ons. This board has no backup battery for the GPS almanac (unlike the Feather build's optional CR1220), so it's plausible every power-cycle needs close to a full cold-start wait, not just the very first one. Give it real time (30+ minutes) outdoors before assuming something's wrong.
- **It needs a genuinely open sky view.** Indoors, it may never get a fix no matter how long you wait.
- **The onboard antenna has multiple independent reports of being weak** (or occasionally dead from the factory) on this specific board. If you've confirmed the chip is talking (case 2 above) and given it real time outdoors and it's still stuck, an external active GPS antenna via the board's GPS u.FL connector (separate from the LoRa one) is a documented fix others have used — see the "no GPS fix" threads on [community.heltec.cn](http://community.heltec.cn) if you land here.

### Case

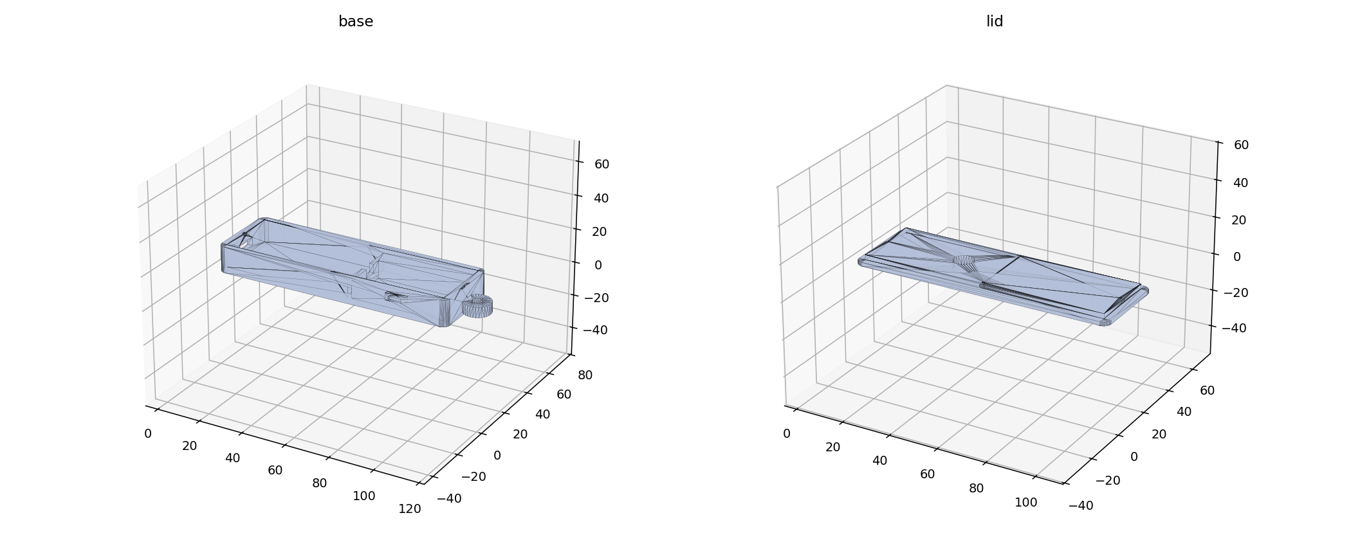
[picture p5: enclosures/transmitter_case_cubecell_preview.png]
Preview of the CubeCell transmitter case


`enclosures/transmitter_case_cubecell.scad` follows the same conventions as the Feather case: snap-lid-and-glue closure and a parachute tie tab. Five things are different because the hardware is different:

- **Slimmed down, with rounded corners.** The board/battery pocket clearances were tightened a bit (still a snug hand-fit, not a press-fit — fine for a case that's glued shut once and not reopened), shaving a couple mm off every outer dimension. The 4 vertical corners are also rounded now instead of sharp 90-degree edges — more comfortable to hold, and it genuinely helps the case slide into a round airframe tube, since a rounded rectangle's bounding circle is smaller than a sharp-cornered one's. Only the outer surfaces are rounded; the interior pockets, cutouts, and lip/skirt stay plain rectangles since they're already inset clear of the rounding.
- **The lid's snap bumps seat into a real detent, not just a flat wall.** Earlier versions of this case copied the Feather case's snap bumps as-is — small nubs that press against a flat wall inside the base's lip cavity with only friction holding them, and barely any interference at that (about 0.05mm after accounting for the fit clearance). It would go on but never really click. This case now cuts a small matching dimple into the lip cavity for each bump, at the exact height the bump reaches when the lid is fully seated, and gives the bumps more interference (0.2mm net instead of 0.05mm) — the bump rubs going in, then relaxes into the dimple right as the lid bottoms out, so you feel an actual click and it resists pulling back off instead of just resting there.
- **No verified mounting-hole spec** is published for this board, so the case relies on a snug pocket fit rather than screw posts (see the comment in the file).
- **The antenna hole is cut through the top of the lid** rather than a side wall, sized generously and centered, since a u.FL pigtail is flexible enough to reach an opening almost anywhere above the board — a deliberate choice to avoid guessing a tight side-wall position from an unverified connector location.
- **The USB cutout is centered on the electronics bay's width by construction.** It used to be a hardcoded guess (`usb_offset = 6.0`) that was noticeably off-center. It's now derived from the board pocket's actual width (`usb_offset = (elec_pocket_w - usb_w) / 2`), so it stays centered even if you change the board clearance elsewhere in the file. If your board's USB port genuinely isn't centered on the board width, nudge `usb_center_bias` (not `usb_offset` directly) to shift it.
- **The inline power switch mount is sized for a specific part** — an **SS12D00-G4** mini slide switch (body 8.7 x 3.7 x 3.7mm, lever 1.5 x 1.5 x 4mm, from the manufacturer's dimensioned drawing) — instead of a generic guessed cutout. It's a keyed pocket on the battery bay's front wall, centered along that bay's length: a narrow outer slot only the slide lever pokes through, and a wider pocket behind it (open to the battery bay's interior) that captures the switch body, so it can't pull back out through the narrow slot. Two small retention bumps (the same idea as the lid's snap bumps, just scaled down) protrude into the pocket from its top and bottom faces — press the switch body in from inside the case and it snaps past them with a "click" and stays put, no glue needed to keep it from rattling loose (though a dab is still fine as extra insurance). It's positioned away from the tie tab on purpose — an earlier version of this case put the switch cutout on the tie tab's end wall, which looked like a stray hole and weakened the same wall the tie tab needs to stay solid. **Height note:** the switch mount sits in the headroom above the battery, not centered in the full case height — an earlier version centered it in the full height, which overlapped the battery's footprint by about 0.85mm and blocked it from sliding fully into the bay. The mount now derives its height from the actual battery envelope (`batt_top_z`) so it can't collide with the battery regardless of other dimensions. If you use a different slide switch, resize `sw_body_l` / `sw_body_w` / `sw_body_h` / `sw_lever_w` at the top of the file to match its drawing (and check `sw_bump_r`/`sw_bump_protrude` still make sense for its body thickness).

As always: print the base first, test-fit your actual board, battery, and switch before printing the lid.

## Packet format (for reference, if you want to extend this later)

Both transmitter sketches and the receiver share this 23-byte struct — keep all three in sync if you add fields:

```c
struct RocketPacket {
  uint32_t seq;          // increments every packet
  float    lat;
  float    lon;
  float    alt_m;
  float    hdop;          // horizontal dilution of precision - lower is
                           // better geometry/accuracy; 99.9 = not reported yet
  uint8_t  sats;
  uint8_t  fixValid;     // 1 = GPS fix valid, 0 = no fix yet
  uint8_t  battPercent;  // transmitter's own battery estimate, 0-100
};
```

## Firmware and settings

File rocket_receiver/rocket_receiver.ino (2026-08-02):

/*
  ROCKET TRACKER - RECEIVER
  Version: v11 - pushed 2026-08-02 UTC. This is when the source itself
           was last changed - update it whenever this file changes. It's
           deliberately separate from the "Firmware built" timestamp printed
           to Serial at boot, which only tells you when THAT PARTICULAR
           UPLOAD was compiled - not useful if you write code and don't get
           around to flashing it until hours (or days) later. v11 disables
           the AP's DHCP default-route advertisement so phones keep
           cellular data (and Maps) available while connected - see
           disableApDefaultRoute() below.
  Board:  Meshnology N30 (ESP32-S3 + SX1262, Heltec WiFi LoRa 32 V3 architecture)
  Role:   Handheld unit. Listens for LoRa packets from the rocket, shows the
          latest fix (plus height above the pad and max height reached) on
          the onboard OLED, and hosts a WiFi hotspot with a web page that has
          a one-tap "Navigate" link (opens your phone's map app with
          turn-by-turn directions to the rocket).

  ------------------------------------------------------------------------
  LIBRARIES YOU NEED (Arduino IDE > Tools > Manage Libraries):
    - "RadioLib" by Jan Gromes
    - "U8g2" by oliver (for the OLED)
  (WiFi.h and WebServer.h ship with the ESP32 board package - no separate install.)

  BOARD PACKAGE:
    - Arduino IDE > Tools > Board > Boards Manager > install "esp32" by Espressif Systems
    - Select board: "ESP32S3 Dev Module" (this clone doesn't have its own board
      entry, so a generic ESP32-S3 profile is what you want)
    - Enable USB CDC on Boot if you want serial monitor output over the same
      USB-C cable (Tools > USB CDC On Boot > Enabled)
  ------------------------------------------------------------------------

  PIN NOTE: The pin numbers below match the standard Heltec WiFi LoRa 32 V3
  layout, which this board is based on. Meshnology's product photos include a
  pinout diagram - double check against that before your first flash, since
  clone boards occasionally shift a pin or two.

  PACKET FORMAT (must match the transmitter sketch exactly):
    uint32_t seq, float lat, float lon, float alt_m, float hdop, uint8_t sats,
    uint8_t fixValid, uint8_t battPercent
    Total size: 23 bytes.
*/

#include <RadioLib.h>
#include <U8g2lib.h>
#include <Wire.h>
#include <WiFi.h>
#include <WebServer.h>
#include "esp_sleep.h"
#include "esp_netif.h"

// ---------------------------------------------------------------------
// CONFIGURE ME
// ---------------------------------------------------------------------

// LoRa (SX1262) pins - standard Heltec WiFi LoRa 32 V3 layout
#define LORA_CS    8
#define LORA_DIO1  14
#define LORA_RST   12
#define LORA_BUSY  13
#define LORA_SCK   9
#define LORA_MISO  11
#define LORA_MOSI  10

// OLED (SSD1306 128x64) pins
#define OLED_SDA   17
#define OLED_SCL   18
#define OLED_RST   21

// Some Heltec V3 / clone boards gate power to the OLED and other onboard
// peripherals through this "Vext" pin - it must be driven LOW to turn them on.
// If your OLED stays blank, this is the first thing to check/remove.
#define VEXT_CTRL  36

// LoRa radio settings - MUST MATCH THE TRANSMITTER EXACTLY
#define LORA_FREQ_MHZ     915.0
#define LORA_BW_KHZ       125.0
#define LORA_SF           9
#define LORA_CR           7
#define LORA_SYNC_WORD    0x12
#define LORA_TX_POWER_DBM 17    // only used if this board ever transmits; harmless otherwise
#define LORA_TCXO_VOLTAGE 1.6   // Heltec V3 boards use a TCXO - this value is required for reliable init

// WiFi hotspot the phone connects to
#define AP_SSID "RocketTracker"
#define AP_PASS "findmyrocket"   // WPA2 requires 8+ characters

// If no packet arrives for this long, the web page/OLED will flag the data as stale
#define STALE_AFTER_MS 15000

// There's no physical power switch on this board, but the top "PRG" button
// is wired to a real, readable GPIO - GPIO0, confirmed against the Heltec
// WiFi LoRa 32 V3 reference library, since this board shares that pinout.
// The BOTTOM "Reset" button is different: it's hardwired straight to the
// chip's reset line in hardware and never passes through your code, so it
// can only ever do an instant hard reboot - it can't be used for this.
#define PRG_BUTTON_PIN 0
#define SLEEP_HOLD_MS  1000   // how long to hold PRG to trigger sleep

// Batteries below this we flag with "!" on-screen, same as stale GPS data.
#define LOW_BATTERY_PERCENT 20

// GPS gives altitude in meters; everything shown to the user is feet instead.
#define METERS_TO_FEET 3.28084f

// ---------------------------------------------------------------------

#pragma pack(push, 1)
struct RocketPacket {
  uint32_t seq;
  float    lat;
  float    lon;
  float    alt_m;
  float    hdop;          // horizontal dilution of precision - lower is
                           // better geometry/accuracy; 99.9 = not reported yet
  uint8_t  sats;
  uint8_t  fixValid;
  uint8_t  battPercent;  // transmitter's own LiPo charge estimate, 0-100
};
#pragma pack(pop)

SX1262 radio = new Module(LORA_CS, LORA_DIO1, LORA_RST, LORA_BUSY);
U8G2_SSD1306_128X64_NONAME_F_HW_I2C u8g2(U8G2_R0, /* reset=*/ OLED_RST, /* clock=*/ OLED_SCL, /* data=*/ OLED_SDA);
WebServer server(80);

volatile bool loraFlag = false;
void onLoraReceive() {
  loraFlag = true;
}

RocketPacket lastPacket = {0, 0.0f, 0.0f, 0.0f, 99.9f, 0, 0, 0};
bool haveEverReceived = false;
uint32_t lastRxMillis = 0;
uint32_t packetsReceived = 0;
uint32_t packetsLost = 0; // best-effort, based on sequence gaps

// Altitude tracking. GPS altitude is Mean Sea Level (MSL), which is not a very
// useful number to look at mid-flight - what you actually want is height above
// the launch pad. We capture the FIRST valid fix we ever receive as "ground
// level" and report everything after that as a delta from it. This means you
// should power the transmitter on while it's already sitting on the pad,
// before launch, so the baseline is accurate. Rebooting the receiver resets
// the baseline and max height.
bool haveAltBaseline = false;
float baselineAltM = 0.0f;
float maxHeightAboveGroundM = 0.0f;

// Rolling log of height-above-pad for the web page's live altitude graph.
// One packet arrives per second, so this is ~30 minutes of flight history -
// plenty for any model rocket flight, and only 7.2KB of RAM (this board has
// ~277KB free), so there's no real memory pressure here. Once full, new
// points stop recording rather than overwriting old ones, so the graph
// still shows the actual flight instead of scrolling it away - tap "New
// Launch" on the web page (or power-cycle the receiver) to reset it and
// start a fresh graph/baseline for the next flight.
#define MAX_ALT_SAMPLES 1800
float altSamplesM[MAX_ALT_SAMPLES];
uint16_t altSampleCount = 0;

// GPS altitude typically has more error than horizontal position (commonly
// +/-30-50 feet without differential correction) - treat this as a rough
// estimate, not a precise altimeter reading.

// All internal math stays in meters (what the GPS actually reports, and
// what's on the wire in RocketPacket) - this is the only place it becomes
// feet, right at the point of display.
float metersToFeet(float m) {
  return m * METERS_TO_FEET;
}

void setup() {
  Serial.begin(115200);
  delay(200);
  Serial.println(F("Rocket receiver booting..."));
  // __DATE__/__TIME__ are filled in by the compiler at build time, so this
  // always reflects the actual firmware running on the board - no manual
  // version number to remember to bump before every upload.
  Serial.print(F("Firmware built: "));
  Serial.print(F(__DATE__));
  Serial.print(F(" "));
  Serial.println(F(__TIME__));

  pinMode(PRG_BUTTON_PIN, INPUT_PULLUP);

  if (esp_sleep_get_wakeup_cause() == ESP_SLEEP_WAKEUP_EXT0) {
    Serial.println(F("Woke up from sleep (PRG button press)."));
  }

  // Power up the OLED / Vext rail (see comment above VEXT_CTRL)
  pinMode(VEXT_CTRL, OUTPUT);
  digitalWrite(VEXT_CTRL, LOW);
  delay(50);

  // Note: the U8g2 constructor above was given the clock/data pins directly,
  // which handles the Wire setup for this non-default I2C pin pair - no
  // separate Wire.begin() call needed here.
  u8g2.begin();
  drawSplash();
  delay(1500); // hold the splash (and its "hold PRG to sleep" hint) long enough to read

  // LoRa radio needs its own SPI pins configured explicitly on this board
  SPI.begin(LORA_SCK, LORA_MISO, LORA_MOSI, LORA_CS);
  int state = radio.begin(LORA_FREQ_MHZ, LORA_BW_KHZ, LORA_SF, LORA_CR,
                           LORA_SYNC_WORD, LORA_TX_POWER_DBM, 8,
                           LORA_TCXO_VOLTAGE, false);
  if (state != RADIOLIB_ERR_NONE) {
    Serial.print(F("Radio init failed, code "));
    Serial.println(state);
    drawError("Radio init failed");
    while (true) { delay(1000); }
  }

  radio.setDio1Action(onLoraReceive);
  radio.startReceive();
  Serial.println(F("Radio listening..."));

  // Start the WiFi hotspot + web server
  WiFi.mode(WIFI_AP);
  WiFi.softAP(AP_SSID, AP_PASS);
  disableApDefaultRoute();
  Serial.print(F("AP started. Connect to WiFi \""));
  Serial.print(AP_SSID);
  Serial.print(F("\" then open http://"));
  Serial.println(WiFi.softAPIP());

  server.on("/", handleRoot);
  server.on("/newlaunch", handleNewLaunch);
  server.begin();
}

// This board has no internet uplink of its own - it's a local-only hotspot.
// But by default, ESP32's DHCP server still advertises itself as the
// network's default gateway (DHCP option 3), which is exactly what a real
// router would do. Phones take that at face value and route ALL traffic
// through this WiFi network once connected - including the "Navigate to
// Rocket" tap, which needs the phone's own cellular data to reach Google
// Maps' servers. Result: connect to RocketTracker, tap Navigate, Maps
// fails to load, because the phone stopped using cellular the moment it
// joined this network.
//
// The fix: strip the router option out of the DHCP offer entirely. With
// no gateway advertised, the phone correctly treats this network as
// "local-only, no internet" - it still uses this WiFi to reach the
// receiver's own web page (same subnet, no gateway needed for that), but
// falls back to cellular data for anything that actually needs the
// internet, Maps included. This is the same trick most WiFi-based IoT
// setup flows use for exactly this reason.
//
// Heads up: your phone may show a "No internet, stay connected?" prompt
// the first time it joins - that's expected and correct here, not a sign
// anything's wrong. Tap to stay connected.
void disableApDefaultRoute() {
  esp_netif_t* apNetif = esp_netif_get_handle_from_ifkey("WIFI_AP_DEF");
  if (apNetif == nullptr) {
    Serial.println(F("AP DHCP: couldn't get netif handle - default route NOT disabled (Maps may fail to load while connected)."));
    return;
  }

  // Options can only be changed while the DHCP server is stopped, so
  // bounce it - this runs once at boot, well before any phone has had a
  // chance to connect and request a lease.
  esp_netif_dhcps_stop(apNetif);
  uint8_t offerRouter = 0; // 0 = leave DHCP option 3 (router) out of offers
  esp_err_t err = esp_netif_dhcps_option(apNetif, ESP_NETIF_OP_SET,
                                          ESP_NETIF_ROUTER_SOLICITATION_ADDRESS,
                                          &offerRouter, sizeof(offerRouter));
  esp_netif_dhcps_start(apNetif);

  if (err == ESP_OK) {
    Serial.println(F("AP DHCP: default route disabled - phones should keep cellular data available for Maps."));
  } else {
    Serial.print(F("AP DHCP: failed to disable default route, err="));
    Serial.println((int)err);
  }
}

void loop() {
  checkSleepButton();
  server.handleClient();

  if (loraFlag) {
    loraFlag = false;
    handleLoraPacket();
  }

  // Periodically refresh the OLED even without new packets, so the
  // "seconds since last fix" counter keeps ticking.
  static uint32_t lastOledRefresh = 0;
  if (millis() - lastOledRefresh > 1000) {
    lastOledRefresh = millis();
    drawStatus();
  }
}

void handleLoraPacket() {
  RocketPacket incoming;
  int state = radio.readData((uint8_t*)&incoming, sizeof(incoming));
  radio.startReceive(); // always re-arm, even on a bad read

  if (state != RADIOLIB_ERR_NONE) {
    Serial.print(F("Read failed, code "));
    Serial.println(state);
    return;
  }

  if (haveEverReceived && incoming.seq > lastPacket.seq + 1) {
    packetsLost += (incoming.seq - lastPacket.seq - 1);
  }

  lastPacket = incoming;
  haveEverReceived = true;
  lastRxMillis = millis();
  packetsReceived++;

  if (lastPacket.fixValid) {
    if (!haveAltBaseline) {
      baselineAltM = lastPacket.alt_m;
      haveAltBaseline = true;
    }
    float heightAboveGround = lastPacket.alt_m - baselineAltM;
    if (heightAboveGround > maxHeightAboveGroundM) {
      maxHeightAboveGroundM = heightAboveGround;
    }
    if (altSampleCount < MAX_ALT_SAMPLES) {
      altSamplesM[altSampleCount++] = heightAboveGround;
    }
  }

  Serial.print(F("Received #"));
  Serial.print(lastPacket.seq);
  Serial.print(F(" fix="));
  Serial.print(lastPacket.fixValid);
  Serial.print(F(" lat="));
  Serial.print(lastPacket.lat, 6);
  Serial.print(F(" lon="));
  Serial.print(lastPacket.lon, 6);
  Serial.print(F(" sats="));
  Serial.print(lastPacket.sats);
  Serial.print(F(" hdop="));
  Serial.println(lastPacket.hdop, 1);

  drawStatus();
}

// ---------------------------------------------------------------------
// Power button (PRG)
// ---------------------------------------------------------------------
// No physical power switch on this board - instead, holding the top PRG
// button for a second puts the ESP32 into deep sleep: LoRa radio, OLED, and
// WiFi radio all powered down to a few microamps (versus tens of mA while
// running), which is the difference between the battery lasting weeks on
// the shelf versus days. Pressing PRG again wakes it with a full reboot -
// same as flipping a power switch back on, just without a switch to buy.
uint32_t buttonPressStartMillis = 0;

void checkSleepButton() {
  bool pressed = (digitalRead(PRG_BUTTON_PIN) == LOW);

  if (pressed && buttonPressStartMillis == 0) {
    buttonPressStartMillis = millis();
  } else if (!pressed) {
    buttonPressStartMillis = 0;
  }

  if (pressed && buttonPressStartMillis != 0 &&
      millis() - buttonPressStartMillis >= SLEEP_HOLD_MS) {
    goToSleep();
  }
}

void goToSleep() {
  u8g2.clearBuffer();
  u8g2.setFont(u8g2_font_6x10_tf);
  u8g2.drawStr(0, 10, "Powering down...");
  u8g2.drawStr(0, 24, "Press PRG to wake");
  u8g2.sendBuffer();

  // Wait for release - the wakeup source armed below triggers on the pin
  // going LOW, which it still is right now while the button is held.
  // Without this, the board would deep-sleep and instantly wake back up.
  while (digitalRead(PRG_BUTTON_PIN) == LOW) {
    delay(10);
  }
  delay(200); // debounce

  WiFi.softAPdisconnect(true);
  WiFi.mode(WIFI_OFF);
  radio.sleep();        // put the LoRa radio in its own low-power sleep mode
  u8g2.setPowerSave(1);  // turn the OLED panel off

  // Cut power to the OLED (and anything else on the Vext rail): let the pin
  // float, the board's own pull-up holds it high, which switches the Vext
  // MOSFET off. This is the same approach the board's official support
  // library uses for this exact rail.
  pinMode(VEXT_CTRL, INPUT);

  esp_sleep_enable_ext0_wakeup((gpio_num_t)PRG_BUTTON_PIN, 0); // wake on LOW
  esp_deep_sleep_start();
  // Execution never reaches here - waking from deep sleep restarts the chip
  // from scratch, same as setup() running after a fresh power-on.
}

// ---------------------------------------------------------------------
// OLED
// ---------------------------------------------------------------------

void drawSplash() {
  u8g2.clearBuffer();
  u8g2.setFont(u8g2_font_6x10_tf);
  u8g2.drawStr(0, 10, "Rocket Tracker");
  u8g2.drawStr(0, 24, "Starting radio...");
  u8g2.drawStr(0, 44, "Hold PRG 1s: sleep");

  // Build date so you can glance at the screen and confirm this is the
  // firmware you meant to flash, without needing a serial monitor attached.
  char buildLine[24];
  snprintf(buildLine, sizeof(buildLine), "Built %s", __DATE__);
  u8g2.drawStr(0, 58, buildLine);

  u8g2.sendBuffer();
}

void drawError(const char* msg) {
  u8g2.clearBuffer();
  u8g2.setFont(u8g2_font_6x10_tf);
  u8g2.drawStr(0, 10, "ERROR:");
  u8g2.drawStr(0, 24, msg);
  u8g2.sendBuffer();
}

void drawStatus() {
  u8g2.clearBuffer();
  u8g2.setFont(u8g2_font_6x10_tf);

  char line[32];

  snprintf(line, sizeof(line), "AP: %s", AP_SSID);
  u8g2.drawStr(0, 9, line);

  // Battery line replaces the old static IP display - the AP's IP is always
  // the standard ESP32 default (http://192.168.4.1, documented in the setup
  // guide), so it's not worth a whole row versus live battery telemetry.
  // Only the transmitter's battery shows here - this board's own battery
  // sensing was tried and removed; see SETUP_README.md's "Battery status"
  // section for why (confirmed hardware limitation on this board).
  if (haveEverReceived) {
    snprintf(line, sizeof(line), "TX Batt: %d%%%s",
             lastPacket.battPercent, lastPacket.battPercent < LOW_BATTERY_PERCENT ? "!" : "");
  } else {
    snprintf(line, sizeof(line), "TX Batt: --");
  }
  u8g2.drawStr(0, 19, line);

  if (!haveEverReceived) {
    u8g2.drawStr(0, 33, "Waiting for signal...");
  } else {
    uint32_t ageMs = millis() - lastRxMillis;
    bool stale = ageMs > STALE_AFTER_MS;

    // Abbreviated (S:/F:/H: instead of Sats:/Fix:/HDOP:) to leave room for
    // all three on one row at this font size - the web page spells them out
    // in full. HDOP is the number to watch if a fix seems imprecise: under
    // 2 is good satellite geometry, over 5 means don't trust it for
    // anything precise even though it says "fix". No separate "Xs ago"
    // row fits at this font size, so instead of a bare "!" flag, a stale
    // reading shows its actual age in parens right after the fix letter -
    // costs no extra space when data's fresh, gives the real number
    // instead of just a flag when it's not.
    char staleSuffix[12] = "";
    if (stale) {
      snprintf(staleSuffix, sizeof(staleSuffix), "(%lus)", ageMs / 1000);
    }
    snprintf(line, sizeof(line), "S:%d F:%s%s H:%.1f", lastPacket.sats,
             lastPacket.fixValid ? "Y" : "N", staleSuffix, lastPacket.hdop);
    u8g2.drawStr(0, 31, line);

    snprintf(line, sizeof(line), "Lat: %.5f", lastPacket.lat);
    u8g2.drawStr(0, 42, line);

    snprintf(line, sizeof(line), "Lon: %.5f", lastPacket.lon);
    u8g2.drawStr(0, 53, line);

    if (haveAltBaseline) {
      float heightAboveGround = lastPacket.alt_m - baselineAltM;
      snprintf(line, sizeof(line), "H:%.0fft Max:%.0fft",
               metersToFeet(heightAboveGround), metersToFeet(maxHeightAboveGroundM));
    } else {
      snprintf(line, sizeof(line), "Alt(MSL): %.0fft", metersToFeet(lastPacket.alt_m));
    }
    u8g2.drawStr(0, 64, line);
  }

  u8g2.sendBuffer();
}

// ---------------------------------------------------------------------
// Web server
// ---------------------------------------------------------------------

// Resets the altitude baseline, max-height tracker, and graph buffer so the
// next valid GPS fix becomes the new "ground level" - lets you run multiple
// flights in a day without power-cycling the receiver between each one.
void handleNewLaunch() {
  altSampleCount = 0;
  haveAltBaseline = false;
  baselineAltM = 0.0f;
  maxHeightAboveGroundM = 0.0f;
  Serial.println(F("New Launch: altitude baseline and graph reset."));
  server.sendHeader("Location", "/");
  server.send(303);
}
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

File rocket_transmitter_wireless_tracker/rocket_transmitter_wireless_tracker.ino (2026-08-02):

/*
  ROCKET TRACKER - TRANSMITTER (Heltec Wireless Tracker V2 alternative)
  Version:  v6 - pushed 2026-08-02 UTC. This is when the source itself
            was last changed - update it whenever this file changes (same
            convention as the other sketches in this repo). GPS still not
            confirmed getting a clean fix on real hardware as of this
            version - added a GNSS reboot-banner detector to test the
            leading hypothesis (Vext power brownout resetting the chip
            mid-search) - see the troubleshooting note near GPS_RESET_PIN
            below for the active investigation.
  Board:    Heltec Wireless Tracker V2 (ESP32-S3FN8 + SX1262 LoRa radio +
            UC6580 GNSS + 0.96" ST7735 TFT, all on one small board with a
            built-in RF front-end amplifier for extra LoRa range)
  Role:     Third option for rocket_transmitter/rocket_transmitter.ino -
            same job (read GPS once a second, pack it into the same binary
            packet, send it over LoRa), same receiver sketch, no changes
            there. Replaces the CubeCell alternative: CubeCell GPS is on
            Heltec's own "Phaseout" list, and its onboard GPS antenna has
            multiple independent weak/dead-on-arrival reports on Heltec's
            community forum. This board uses a different, better-regarded
            GNSS chip (UC6580, dual-frequency, multi-constellation) and is
            an actively-sold, actively-supported product.

  ------------------------------------------------------------------------
  PIN MAP - WHERE THIS CAME FROM
    Heltec doesn't publish a plain pin-name table for this board (just a
    schematic PDF and a pinout image), so every pin below is taken from
    Meshtastic's official firmware source for this exact board
    (variants/esp32s3/heltec_wireless_tracker_v2/variant.h in
    github.com/meshtastic/firmware) - real, shipped, community-tested
    firmware for this specific hardware, not a guess from a datasheet.
  ------------------------------------------------------------------------

  RF FRONT-END - WHY THERE ARE EXTRA GPIO WRITES BEFORE RADIO.BEGIN()
    Unlike the Feather/CubeCell builds, this board has a KCT8103L front-end
    chip between the SX1262 and the antenna - it's what gets LoRa TX power
    up to the rated 28dBm instead of the SX1262 chip's own ~22dBm ceiling,
    and it also provides RX gain (not used here - this sketch only
    transmits, never listens). Three extra GPIO pins control it:
      - PA_POWER (7):  powers the front-end chip's own regulator
      - PA_CSD   (4):  chip enable (HIGH = on)
      - PA_CTX   (5):  HIGH = transmit-amplify path (also fine at rest,
                        since this sketch never receives)
    All three are set once at boot and left alone - no need to toggle them
    per-packet. The chip's 4th control line (CPS, TX/RX path select) is
    wired directly to the SX1262's own DIO2 pin, not to an ESP32 GPIO -
    radio.setDio2AsRfSwitch(true) below tells the SX1262 to drive that pin
    itself, so nothing else to do for that one.

  ------------------------------------------------------------------------
  DISPLAY / GPS SHARE ONE POWER RAIL - WHY THE BUTTON ONLY TOGGLES BACKLIGHT
    On the CubeCell build, the OLED and GPS were powered separately, so the
    status screen could be fully powered off between checks to save
    battery. On this board, Vext (GPIO3) powers the GPS, its LNA, AND the
    display controller all together - there's no separate switch for the
    display alone. Since GPS needs to stay powered for the whole flight
    anyway, there's no real battery-saving reason to power the display
    controller off and on. Instead, the button (see below) only toggles
    the TFT backlight (a separate pin, TFT_BL) - the display keeps
    receiving fresh draws every packet either way, so the instant you turn
    the backlight on, it's already showing current status, no lag.

  ------------------------------------------------------------------------
  BOARD PACKAGE / LIBRARIES YOU NEED
    - Arduino IDE > Preferences > Additional Board Manager URLs, add:
        https://espressif.github.io/arduino-esp32/package_esp32_index.json
    - Tools > Board > Boards Manager > install "esp32" (Espressif Systems)
    - Select board: "ESP32S3 Dev Module"
    - Tools > USB CDC On Boot: "Enabled" (needed to see Serial output over
      the USB-C port without a separate UART adapter)
    - Library Manager: install "RadioLib" (Jan Gromes), "TinyGPSPlus"
      (Mikal Hart), "Adafruit GFX Library", and "Adafruit ST7735 and
      ST7789 Library" (both Adafruit) - same RadioLib/TinyGPSPlus already
      used by the other sketches in this repo, plus the two display
      libraries this board's TFT needs that the OLED builds didn't.
  ------------------------------------------------------------------------

  PACKET FORMAT (identical to every other transmitter build in this repo -
  the receiver can't tell which transmitter sent a packet, and doesn't
  need to):
    uint32_t seq         - increments every packet, lets receiver detect drops
    float    lat         - degrees
    float    lon         - degrees
    float    alt_m       - meters
    float    hdop        - horizontal dilution of precision, lower = better
                            geometry/accuracy (under ~2 is good, over ~5 is
                            poor) - 99.9 means the GPS hasn't reported one yet
    uint8_t  sats        - number of satellites used in fix
    uint8_t  fixValid    - 1 = GPS has a valid fix this packet, 0 = no fix yet
    uint8_t  battPercent - this board's own LiPo charge estimate, 0-100
  Total size: 23 bytes.
*/

#include <SPI.h>
#include <string.h>
#include <RadioLib.h>
#include <TinyGPSPlus.h>
#include <Adafruit_GFX.h>
#include <Adafruit_ST7735.h>

// ---------------------------------------------------------------------
// CONFIGURE ME
// ---------------------------------------------------------------------

// LoRa (SX1262) pins - from Meshtastic's heltec_wireless_tracker_v2
// variant.h (see header comment above). Same CS/DIO1/RST/BUSY/SCK/MISO/
// MOSI numbering convention as the receiver's Meshnology N30 board, which
// is no coincidence - Heltec reuses this pin layout across most of their
// ESP32+SX1262 boards.
#define LORA_CS    8
#define LORA_DIO1  14
#define LORA_RST   12
#define LORA_BUSY  13
#define LORA_SCK   9
#define LORA_MISO  11
#define LORA_MOSI  10

// KCT8103L RF front-end control pins - see "RF FRONT-END" note above.
#define FEM_PA_POWER 7  // front-end regulator enable
#define FEM_PA_CSD   4  // front-end chip enable (HIGH = on)
#define FEM_PA_CTX   5  // HIGH = TX-amplify path
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

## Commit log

2026-07-23 Add project README with overview and Bill of Materials
2026-07-25 Add PRG-button deep sleep/wake to receiver to save battery when idle
2026-07-25 Add battery percentage reporting for both boards
2026-07-25 Show altitude in feet everywhere; fix stale packet-size mention
    [rocket_receiver.ino]
2026-07-25 Add raw battery voltage diagnostic print to help debug 0% reading
2026-07-25 Set explicit ADC resolution/attenuation and add raw ADC count to battery diagnostic
2026-07-25 Fix RX battery reading: hold VBAT_CTRL low permanently instead of toggling per-read
    [rocket_receiver.ino]
2026-07-26 Show RX battery as n/a instead of a misleading 0% when no reading is available
2026-07-26 Document confirmed RX battery hardware limitation (multimeter-verified)
2026-07-26 Remove non-functional RX battery reporting; switch version header to push timestamp
2026-07-27 Add live altitude graph + New Launch reset button to receiver web UI
2026-07-27 Add illustrative sample screenshot of receiver web UI with altitude graph
2026-07-27 Add parametric OpenSCAD case for the transmitter (board stack, battery, switch cutout)
    [transmitter_case.scad]
2026-07-27 Case: replace screw ears with snap-fit+glue closure, add parachute tie tab
    [transmitter_case.scad]
2026-07-27 Case: fix lip so lid actually snaps on, resize battery bay for 300mAh 302040 cell, move antenna cutout to a round hole near the far end
    [transmitter_case.scad]
2026-07-27 Add CubeCell GPS transmitter alternative: firmware, case, docs
    - rocket_transmitter_cubecell.ino: raw point-to-point LoRa firmware for
    Heltec CubeCell GPS (HTCC-AB02S), same 19-byte packet as the Feather
    build, sync word/frequency/BW/SF/CR matched to work with the existing
    receiver sketch unmodified. Compile-and-link verified against the real
    CubeCell board package (v1.4.0) and an ARM cross-compiler - zero errors.
    - enclosures/transmitter_case_cubecell.scad: matching parametric case,
    same snap-lid+glue closure and parachute tie tab as the Feather case,
    antenna hole through the lid top (not a side wall) since this board
    uses a u.FL connector and pigtail instead of a solder-in an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
    [transmitter_case_cubecell.scad]
2026-07-31 Rework CubeCell case switch mount for SS12D00-G4, move off tie-tab wall
    - Removed the old guessed inline-switch cutout from the battery bay's end
    wall, which sat right next to the parachute tie tab and looked like an
    unexplained stray hole.
    - Added a keyed switch pocket on the battery bay's front wall instead,
    sized from the SS12D00-G4 slide switch's dimensioned drawing (body
    8.7x3.7x3.7mm, lever 1.5x1.5x4mm): a narrow outer slot for the lever,
    and a wider captured pocket behind it for the body, open to the
    interior for wiring.
    - Re-rendered and validated in OpenSCAD (aarch64 build) - both parts
    render as simple/manifold solids, no errors.
    - Regenerated the case preview image,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
    [transmitter_case_cubecell.scad]
2026-07-31 CubeCell case: add snap retention bumps to switch pocket
    The switch mount previously relied on a shouldered pocket plus glue to
    hold the SS12D00-G4 in place. Added two small retention bumps (same
    mechanism as the lid's existing snap bumps, scaled down) on the pocket's
    top and bottom faces - the switch body presses past them on insertion
    and they nest against its top/bottom face afterward, holding it with a
    click. Verified the fused geometry two ways: an independent Python edge
    walk on the exported STL (0 non-manifold edges) and OpenSCAD's own
    render report (Simple: yes, same volume count as before the bumps were
    added, meaning they fused into the wall rather than floating separately).
    Caught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
    [transmitter_case_cubecell.scad]
2026-07-31 CubeCell case: give the lid a real snap detent instead of just friction
    The lid went on without ever clicking. Root cause: the snap bumps only
    pressed against a flat wall inside the base's lip cavity (friction only,
    no groove to catch into), and the net interference was tiny - bump
    protrusion (0.35mm) barely exceeded the skirt's fit clearance (0.3mm),
    leaving about 0.05mm of actual squeeze once you account for the gap it
    has to close first. Easy to lose entirely to ordinary FDM print
    tolerance.
    Fix:
    - Cut a small dimple into the base's lip cavity wall for each of the 4
    bumps, positioned at the exact height the bump reaches when the lid
    bottoms out (lip_bump_z, derived from the same skir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
    [transmitter_case_cubecell.scad]
2026-07-31 CubeCell case: fix switch/battery collision and off-center USB cutout
    Switch mount collision: sw_mount_z was centered in the full case height
    (floor to lip), but the battery only occupies the bottom ~4.2mm of that -
    the electronics bay's board+clearance stack is what actually drives
    case_h, leaving real headroom above the battery specifically. Centering
    in the full height put the switch pocket low enough to overlap the
    battery's footprint by about 0.85mm, blocking it from sliding fully in.
    Now derives sw_mount_z from the actual battery envelope (batt_top_z) and
    centers in the headroom above it instead - verified numerically, 1.25mm
    clearance on both sides of the pocket now.
    USB cutout: usb_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
    [transmitter_case_cubecell.scad]
2026-07-31 CubeCell transmitter: add GPS diagnostics for the 'Sats:0 Fix:N' report
    Researched the GPS_Air530Z library source directly (HelTecAutomation's
    CubeCell-Arduino repo) to confirm Air530ZClass publicly extends TinyGPS++,
    so its diagnostic counters (charsProcessed/sentencesWithFix/failedChecksum)
    are available. Added them to the existing per-second serial log so a bench
    tester can tell apart two situations that both show as 'Sats:0 Fix:N' on
    the receiver but need completely different fixes:
    - No data arriving from the GPS chip at all (wiring/board problem)
    - Data arriving fine, just no satellite lock yet (needs time/sky view)
    Also confirmed GPS.begin() already calls setmode(MODE_GPS_BEIDOU_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
    [rocket_transmitter_cubecell.ino]
2026-07-31 CubeCell transmitter: show live GPS/radio status on the onboard OLED
    The HTCC-AB02S has a built-in 0.96in 128x64 OLED that wasn't being used.
    Added a showStatus() function, called once per second alongside the
    existing serial diagnostics, that shows:
    - Fix Y/N and satellite count
    - GPS chip health in plain words - 'chip: NO DATA' (nothing arriving,
    hardware problem), 'chip: searching' (working fine, no fix yet),
    or 'chip: OK' (has a fix) - the same diagnosis this project's docs
    already walk through, now visible on the device itself
    - Running GPS char count
    - Battery % and last packet sequence number
    - Lat/lon once there's a fix
    This solves the practical problem of benc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
    [rocket_transmitter_cubecell.ino]
2026-07-31 CubeCell transmitter: OLED off by default, toggle with user button
    The display was staying on continuously, which draws real power the whole
    flight for a screen nobody's looking at once the rocket's on the pad.
    Changed it to start OFF at boot (no Vext power, no display.init() call
    at all until asked for) and added a button toggle:
    - checkDisplayButton() polls pin P3_3 (the board's user/PRG button,
    confirmed against Heltec's Factory_Test_AB02S.ino) with a simple
    debounced edge-detect, mirroring the same polling style the receiver
    sketch already uses for its own PRG-button sleep/wake, rather than
    attachInterrupt() like Heltec's example - simpler and avoids ISR-safety
    concerns for no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
    [rocket_transmitter_cubecell.ino]
2026-07-31 Add GPS HDOP (fix quality) to the packet - both transmitters + receiver
    Adds float hdop to RocketPacket (19 -> 23 bytes), populated from
    GPS.hdop.hdop() when valid, else a 99.9 sentinel so a not-yet-reported
    HDOP never displays as a misleadingly great 0.0. Updated in all three
    sketches together since they share one wire format:
    - rocket_transmitter.ino (Feather): struct + sendPacket() + serial log
    - rocket_transmitter_cubecell.ino: struct + sendPacket() + serial log +
    OLED showStatus() (HDOP with a good/ok/poor label - the number to check
    before launch if a fix seems less precise than expected)
    - rocket_receiver.ino: struct + serial log + OLED drawStatus() (abbreviated
    to fit - droppe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
    [rocket_receiver.ino, rocket_transmitter.ino, rocket_transmitter_cubecell.ino]
2026-07-31 Slim CubeCell case footprint and round exterior corners
    - Tighten board/battery pocket clearances (board_fit, batt_fit,
    board_vert_clear) to shave a couple mm off every outer dimension -
    still a snug hand-fit since the case is glued shut once, not reopened.
    - Round the 4 vertical exterior corners on both base and lid via a
    hull-of-corner-cylinders rounded_box() helper, applied only to outer
    surfaces (interior pockets/cutouts/lip/skirt stay rectangular, already
    inset clear of the rounding). Helps handling and helps the case slide
    into a round airframe tube (smaller bounding-circle diameter).
    - New footprint: 105.7 x 34.1 x 15.5mm (was 107.3 x 34.9 x 16.0mm).
    - Re-validated: OpenSC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
    [transmitter_case_cubecell.scad]
2026-08-01 Add Wireless Tracker V2 transmitter build (firmware + case)
    Replaces CubeCell GPS as the recommended small-form-factor transmitter:
    CubeCell is on Heltec's Phaseout list and has multiple reported weak/DOA
    onboard GPS antenna units; Wireless Tracker V2 (ESP32-S3 + SX1262 + UC6580
    GNSS + RF front-end amp) is actively sold/supported and uses a better-
    regarded GNSS chip.
    - New rocket_transmitter_wireless_tracker.ino: uses RadioLib directly
    (same library + matching pin numbers as the receiver, unlike CubeCell's
    raw driver workaround), TinyGPSPlus over UC6580's UART at 115200 baud,
    Adafruit ST7735 TFT status display, same 23-byte RocketPacket struct.
    Handles the board's KCT8103L RF front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
    [transmitter_case_wireless_tracker.scad]
2026-08-02 Receiver OLED: show exact staleness age instead of bare '!' flag
    Restores the elapsed-seconds-since-last-packet info that used to share
    the sats/fix row before HDOP was added and squeezed it out (down to just
    a '!' flag). Now the fix indicator shows '(Ns)' in place of the bare '!'
    only when data is stale, so it costs no extra space when fresh but gives
    the real number back when it's not - same info as the web page's 'Last
    update: Xs ago' line, which was never affected (OLED-only regression).
    Compile-verified clean (esp32:esp32:esp32s3, zero errors/warnings).
    [rocket_receiver.ino]
2026-08-02 Wireless Tracker V2 transmitter: show GPS char/checksum counts on TFT
    Serial isn't showing any output for this build in the field yet (likely
    the ESP32-S3 USB CDC On Boot setting, not a code issue), so the same
    chars/checksumFail diagnostic numbers the serial log prints now also show
    on the TFT status screen - lets a no-fix situation be diagnosed entirely
    from the board itself without depending on Serial working.
    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
    [rocket_transmitter_wireless_tracker.ino]
2026-08-02 Fix: force TFT backlight on for a radio-init failure
    Found while investigating a report of a totally blank screen: if
    radio.begin() fails, setup() prints the error and hangs forever in an
    infinite loop - but the backlight defaults OFF at boot and nothing in
    that failure path ever turned it on. A radio init failure was therefore
    completely indistinguishable from a healthy board that just hasn't had
    its button pressed yet - both looked like a blank screen. Now the
    backlight is forced on before drawing the failure message, so a real
    init failure is actually visible instead of silently identical to
    'working fine, just needs the button pressed.'
    Compile-verified clean (esp32:esp32:esp32s3, zero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
    [rocket_transmitter_wireless_tracker.ino]
2026-08-02 Swap GPS UART rx/tx pin roles - field data showed garbled input
    Field test showed chars=N and checksumFail=N both climbing together -
    bytes arriving but essentially none parsing as valid NMEA, which points
    to listening on the wrong physical pin rather than a reception/antenna
    problem. GPS_RX_PIN/GPS_TX_PIN were taken as raw pin numbers from
    Meshtastic's variant.h, but that source never showed the actual
    Serial.begin() call - and 'GPS_RX_PIN' is ambiguous between 'the ESP32's
    own RX pin' (what this file originally assumed) and 'the pin wired to
    the GPS's RX input' (the ESP32's TX pin, from the GPS's point of view).
    Swapped which define is passed as rxPin vs. txPin to test the second
    reading.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
    [rocket_transmitter_wireless_tracker.ino]
2026-08-02 Revert GPS rx/tx swap; stop driving GPS reset pin; catch up version header
    Field test of the rx/tx swap made things worse (total silence instead of
    garbled data), pointing back at the original pin assignment as the
    correct one - reverted. Independently confirmed the UC6580's factory
    baud (115200) is right, ruling that out too. New leading suspect for the
    garbled-data symptom: GPS_RESET_PIN was being actively driven based on
    an unverified guess about Meshtastic's GPS_RESET_MODE polarity - now
    left as a floating input instead, letting the board's own hardware
    default take over rather than a guess that could be actively holding the
    chip in a bad state.
    Also catches up the version header, which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
    [rocket_transmitter_wireless_tracker.ino]
2026-08-02 Wireless Tracker V2: add GNSS reboot-banner detector
    checksumFail=0 across 3.4M+ chars / 48+ min of field testing proved the
    UART link to the GPS is clean, yet zero fix ever. Two Meshtastic GitHub
    issues (#7786, #5088) cover this exact board/chip. #5088 is the more
    credible lead: Vext can brown out under USB-only power and silently
    reset the UC6580 mid-acquisition, over and over, which would look
    exactly like this (clean NMEA each boot, never a completed fix). Added
    feedGpsRebootDetector() to scan the raw UART stream for the chip's boot
    banner - if it fires more than once per session, that confirms the
    chip is resetting, not just slow to find satellites. Count shown on
    Serial and the TFT's d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
    [transmitter_case_cubecell.3mf]
2026-08-02 Receiver: disable AP default-route DHCP advertisement
    Phones connecting to the RocketTracker hotspot were treating it as their
    sole internet route (standard OS behavior once a network hands out a
    default gateway), so tapping Navigate to Rocket couldn't reach Google
    Maps - the phone had stopped using cellular the moment it joined this
    WiFi. This board has no internet uplink to offer in the first place.
    Fix: strip DHCP option 3 (router) from the AP's offers via
    esp_netif_dhcps_option(), so phones treat the network as local-only and
    keep cellular data available for anything that needs real internet,
    while still reaching the receiver's own web page over the same subnet.
    Expect a 'no internet, st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
    [rocket_receiver.ino]
